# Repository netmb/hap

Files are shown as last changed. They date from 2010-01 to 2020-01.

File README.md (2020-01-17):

# This project is no longer maintained! We recommend esphome.io in combination with home-assistant.io as an alternative.
## If you build a lot of HAP-Actors like "HAP-Relais" and would like to continue using it: Use esphome.io with an ESP32 as an drop-in replacment. Works like charm!
Home Automation Project

HA using Atmel-AVR and Web 2.0.



Take a look at the [Wiki-Sites](https://github.com/netmb/hap/wiki) for more Information or if you want to jump-start, check the Installation-Instruction: [Installation](https://github.com/netmb/hap/wiki/Installation)

Some more documenation:

[HAP-CU-TechDok.pdf](https://github.com/netmb/hap/blob/master/doc/HAP-CU-TechDok.pdf?raw=true)

[Hap_QuickStart.pdf](https://github.com/netmb/hap/blob/master/doc/Hap_QuickStart.pdf?raw=true)

If you need support, check out: [hap-users group](https://groups.google.com/d/forum/hap-users)

This thread is also a good source: http://www.mikrocontroller.net/topic/148340#new

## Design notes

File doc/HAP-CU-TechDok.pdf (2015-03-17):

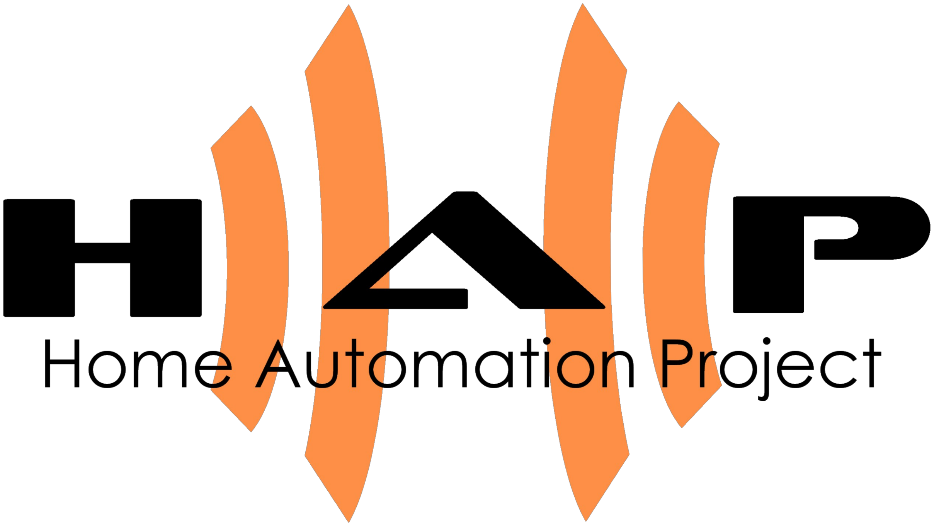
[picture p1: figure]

# Control Unit

Technische Dokumentation

Autor: | Dipl.-Ing. Holger Heuser
Revision: | 1.0 (1)
Zuletzt geändert: | 25. März 2008

Inhaltsverzeichnis

- 2 -

- 3 -

Abbildungsverzeichnis

- 4 -

Tabellenverzeichnis

Tabelle 4.15: AS Codierung der Zeitbasis bei der zeitgesteuerten Weiterleitung.......84

- 5 -

## 1 Einleitung

Die Control Unit stellt innerhalb des HAP (Home Automation Project) die zentrale Komponente dar. Sie nimmt unterschiedlichste Steuer- und Regelaufgaben wahr und arbeitet dabei völlig autonom. So ist es mit Hilfe der Control Unit möglich, Leuchten zu steuern bzw. zu dimmen, alle möglichen Arten von Geräten zu steuern und zu schalten, sowie Messwerte von Sensoren zu erfassen, zu verarbeiten oder weiterzuleiten. Sie bietet eine Infrarot-Schnittstelle zu ihrer Steuerung an und kann
mit | Hilfe | eines | LCD | (Liquid | Crystal | Display) | und | entsprechenden
Eingabekomponenten eine Mensch-Maschine-Schnittstelle realisieren. So lassen sich prinzipiell alle im Haus bzw. in der Wohnung anfallenden Steuerungen und Regelungen realisieren.

Da die Zahl der anschließbaren Geräte durch die Anzahl an Ein- und Ausgängen des verwendeten Mikrocontrollers begrenzt ist, werden für eine Heimsteuerung gewöhnlich mehrere Control Units benötigt. Damit diese untereinander Informationen über den Status der jeweils angeschlossenen Geräte und weitere Nachrichten, die zum gemeinsamen Bewältigen einer komplexen Steueraufgabe nötig sind,
austauschen | können, | besitzt | eine | Control | Unit | mehrere
Kommunikationsschnittstellen bzw. kann mit diesen bestückt werden. So wird in den meisten Fällen auf einen CAN-Bus (Controller Area Network Bus) zurückgegriffen. Es ist aber auch die Kommunikation über Funk möglich.

Für Konfigurationsarbeiten, zur Verwaltung der kompletten Steuerungsanlage, zum Fehlermanagement und zur Steuerung von Geräten über Webbrowser, PDAs, Handys etc. wird eine Central Control Unit eingesetzt, bei der es sich um ein Serversystem mit spezieller Steuerungssoftware handelt. Damit eine Control Unit mit der Central Control Unit kommunizieren kann, wird eine speziell konfigurierte Control Unit eingesetzt, die als Brücke zwischen dem von den Control Units verwendeten Kommunikationssystem und der seriellen oder USB-Schnittstelle der Central Control Unit arbeitet.

Im Allgemeinen wird man die Control Units in Hutschienengehäusen in der Elektroverteilung unterbringen. Dies ist insbesondere dann sinnvoll, wenn zur Ansteuerung von Geräten Leistungsstufen wie Relais oder Dimmerstufen benötigt werden. Die räumliche Nähe erleichtert dann die Verkabelungsarbeiten erheblich. Die

- 6 -

Bauform der Control Unit lässt aber auch die Unterbringung in Schalterdosen zu, was vor allem für die Realisierung einer Mensch-Maschine-Schnittstelle sinnvoll ist, da sich eine solche meist in den Wohnräumen befindet.

Welche Geräte wo und wie an die Control Unit angeschlossen werden können, ist bis auf wenige Restriktionen frei konfigurierbar. Des weiteren ist das Verhalten einer Control Unit in ihrer Umgebung durch komplexe Konfigurationsmöglichkeiten einstellbar. Insbesondere die Konfiguration einer Mensch-Maschine-Schnittstelle ist recht aufwändig. Zur besseren Handhabung und zur Vermeidung von Fehlern steht ein Softwarewerkzeug für diese Arbeiten zur Verfügung, welches die Konfiguration einer Control Unit recht komfortabel gestaltet und nicht nur eine Control Unit dabei berücksichtigt, sondern das System als Ganzes. Die von diesem Werkzeug erzeugten Konfigurationen werden dann in EEPROMs auf der Control Unit gespeichert, so dass diese prinzipiell autark, also ohne die Central Control Unit funktionieren können und auch nach einem Stromausfall problemlos wieder funktionieren.

Der Aufbau und die Funktionsweise der Hardware wird im nächsten Kapitel beschrieben (siehe Kapitel 2 Hardware). Es folgt die Beschreibung des grundlegenden Verhaltens einer Control Unit, ihr Kommunikationsverhalten sowie deren Handhabung hinsichtlich Konfiguration, Management und Wartung (siehe Kapitel 3 Steuerung). Die unterschiedlichen Software Komponenten, die auf einer Control Unit integriert sein können, werden im Kapitel 4 Komponenten erörtert. Schließlich finden sich in Kapitel 5 Tabellen und Übersichten noch einmal Zusammenfassungen aus vorigen Kapiteln bzw. sind einige Sachverhalte anders zusammengestellt, um einen schnelleren Überblick zu bekommen bzw. schnell gezielte Informationen zu finden.

- 7 -

## 2 Hardware

Unter einer Control Unit wird im Allgemeinen nur die fertig bestückte Platine verstanden. Ob diese in einem Hutschienengehäuse zum Einbau in der Elektroverteilung, in einem gewöhnlichen Gehäuse, als Aufsatz einer Leistungsstufe oder direkt in einer Schalterdose untergebracht wird, ist vom jeweiligen Einsatzzweck abhängig. Unten stehende Abbildung zeigt die Control Unit in Draufsicht.

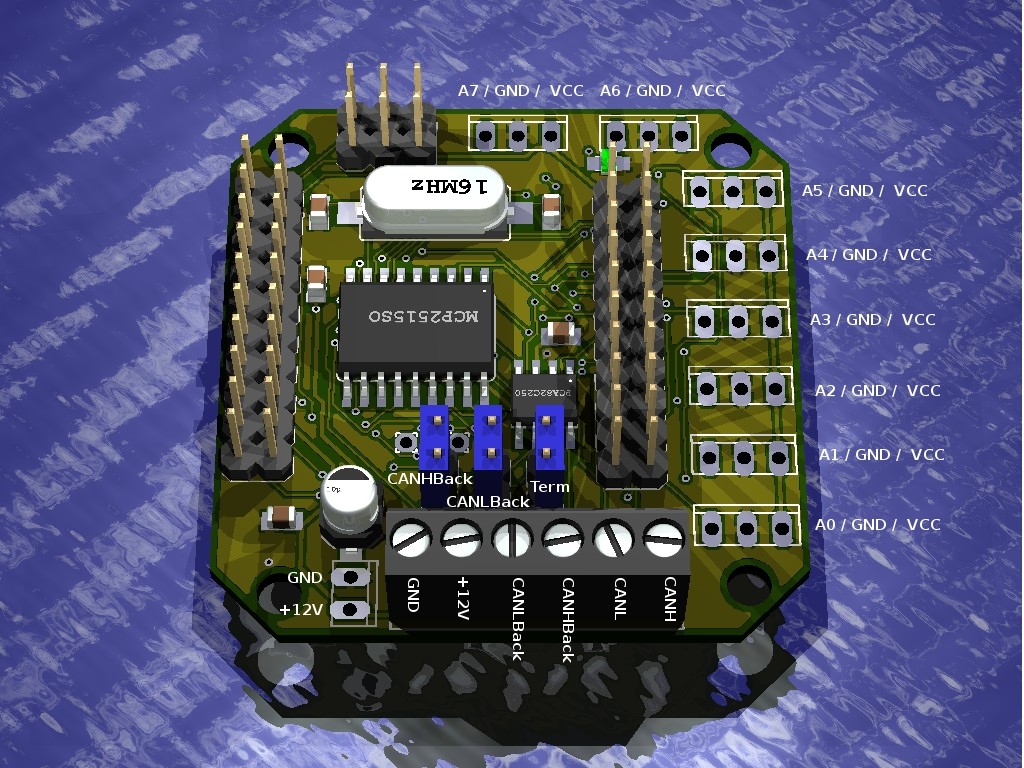
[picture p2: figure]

### 2.1 Schaltung

Der Schaltplan der Control Unit ist auf der nächsten Seite dargestellt. Auf Basis dieses Plans sollen die wichtigsten Komponenten der Unit beschrieben und im folgenden Kapitel auch die Pin-Konfiguration erläutert werden.

- 8 -

Abb. 2.1: Control Unit in der Draufsicht

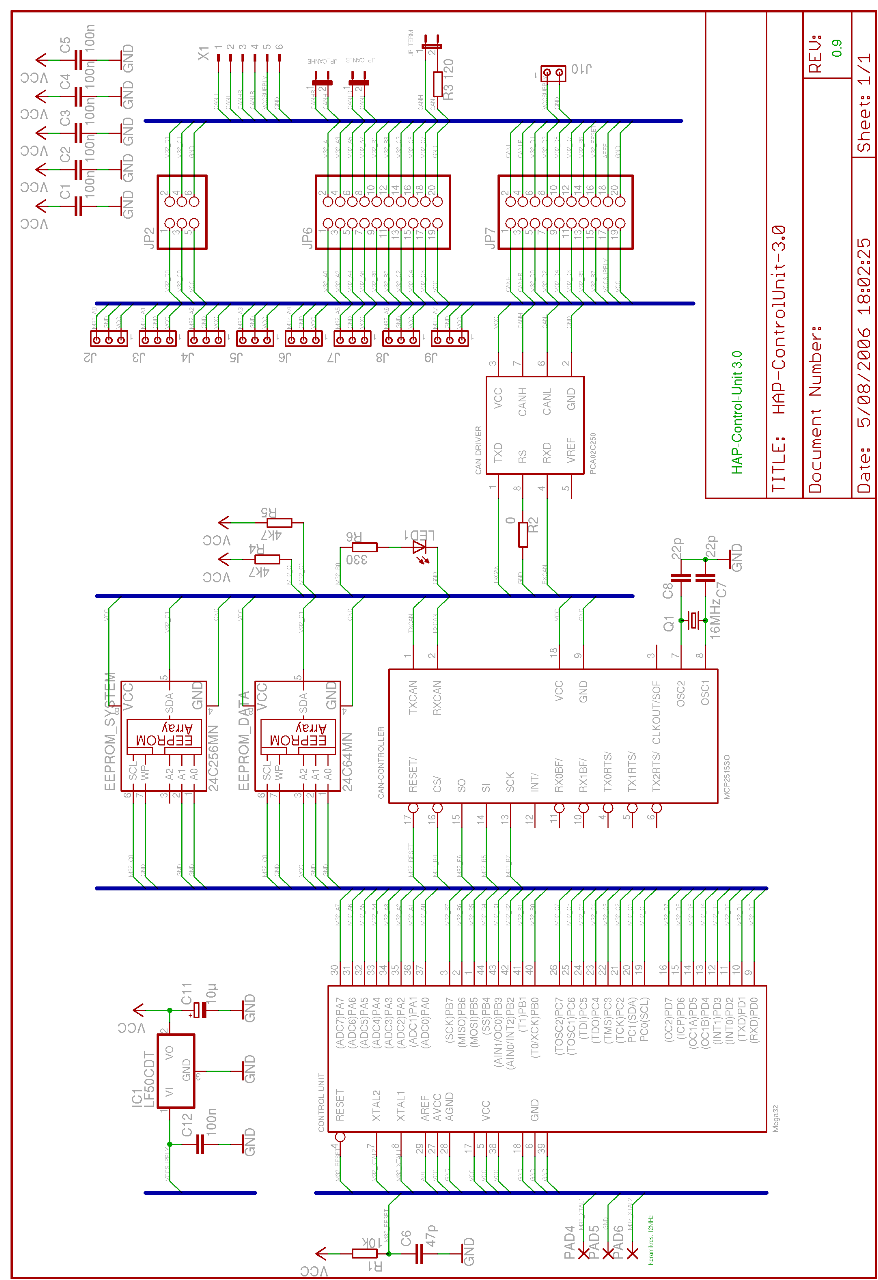
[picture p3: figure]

- 9 -

Abb. 2.2: Schaltplan der Control Unit

In den folgenden Ausführungen wird davon ausgegangen, dass der Schaltplan im Querformat vorliegt, die Schrift also korrekt zum Betrachter ausgerichtet ist. Zu den Details, die auf diesem Plan nicht mehr zu erkennen sind, sei auf den Originalplan verwiesen.

In der oberen linken Ecke des Plans erkennt man die Spannungsversorgung, die mit Hilfe eines Festspannungsreglers die außen anliegende 12 V Gleichspannung in eine intern verwendete 5 V Gleichspannung (VCC) wandelt und diese glättet.

Darunter findet man das Herzstück der Control Unit, den Mikrocontroller. Hier wird ein ATmega32 von ATMEL verwendet. Der Reset-Pin wird nicht verwendet und deshalb über R1 mit VCC verbunden. PAD4 bis PAD6 dienen der Aufnahme eines externen Quarz. Dieser muss eine Frequenz von 12 MHz aufweisen und legt damit die Taktfrequenz des Mikrocontroller auf eben diesen Wert fest.

In der Bildmitte oben sieht man zwei externe EEPROMs der Größe 64 KBit und 256 KBit, die über ein TWI (Two Wire Interface) mit dem Mikrocontroller verbunden sind. Neben dem im Mikrocontroller integriertem EEPROM dienen diese dem Speichern der Konfigurationsdaten der Control Unit und deren Firmware Update.

Rechts unterhalb der EEPROMs ist eine LED zu erkennen, die als optische Signaleinrichtung dient und mit Pin B0 des Mikrocontrollers verbunden ist. An den selben Pin kann auch ein Summer als akustische Unterstützung angeschlossen werden (siehe auch Kapitel 4.3 Buzzer).

Direkt unterhalb der EEPROMS findet man den CAN-Controller (Controller Area Network Controller), der zur Steuerung des CAN-Bus benötigt wird. Dieser bezieht seine Taktfrequenz von einem separatem 16 MHz Quarz (unten rechts) und ist über ein SPI (Serial Peripheral Interface) mit dem Mikrocontroller gekoppelt. Über den rechts daneben befindlichen CAN-Treiber wird dann direkt der CAN-Bus betrieben.

Die drei Jumper am rechten Bildrand stehen von oben nach unten für CANHBack, CANLBack und CANTerm. Ist CANHBack gesteckt, so wird der Anschluss CANH an der Schraubleiste X1 nach CANHBack geschliffen, ansonsten nicht. Für CANLBack gilt dies analog. Der Jumper CANTerm terminiert den CAN-Bus, das heißt, R3 wird zwischen CANH und CANL geschaltet.

- 10 -

### 2.2 Pin-Konfiguration

Die Control Unit besitzt unterschiedliche Steckverbinder und Klemmleisten, die alle für einen spezifischen Zweck zugeschnitten worden sind. Im Folgenden wird deren Belegung und Verwendung näher beschrieben (siehe als Referenz hierzu Abbildung 2.1 Control Unit in der Draufsicht, Kapitel 2.1 Schaltung und 2.3 Dimensionen und Platinenlayout).

Die Klemmleiste X1 dient dem Anschluss an den CAN-Bus. Von links nach rechts ergibt sich die Belegung der Klemmleiste wie folgt.

Klemme | Beschreibung
1 | Ground
2 | Versorgungsspannung (+12 V)
3 | CAN Low Back
4 | CAN High Back
5 | CAN Low
6 | CAN High

Tabelle 2.1: Belegung der CAN Klemmleiste

Wird die Control Unit über den CAN-Bus mit Strom versorgt, so ist die Versorgungsspannung an den Klemmen 1 und 2 anzulegen. Soll die Control Unit über eine Stichleitung an den CAN-Bus angeschlossen werden, so sind die Adern CAN Low und CAN High an Klemme 5 und 6 anzulegen. Soll der CAN-Bus über die Control Unit geschliffen werden, so sind die entsprechenden Jumper zu setzen (siehe Kapitel 2.1 Schaltung) und über die Klemmen 3 und 4 ist der Bus wieder abzugreifen.

Alternativ | zur | Spannungsversorgung | über | den | CAN-Bus | kann | die
Versorgungsspannung auch über den 2-pol. Platinensteckverbinder J10 zugeführt werden (außen liegender Pin ist +12 V, innen liegender Pin ist Ground). Wird die Control Unit aber über den CAN-Bus versorgt, so kann die Versorgungsspannung über J10 für andere Zwecke abgegriffen werden.

Insbesondere, weil der Anschluss analoger und digitaler Sensoren auf Port A des Mikrocontrollers beschränkt ist (siehe Kapitel 4.9 Analoge Eingänge und 4.10 Digitale Eingänge), ist jeder Pin von Port A über einen eigenen Platinensteckverbinder, an

- 11 -dem zusätzlich auch Ground und VCC anliegt, nach außen geführt. Folgende Tabelle zeigt die Stift-Belegung von unten nach oben und von rechts nach links.
Steckverb. | Links | Mitte | Rechts
J2 | Pin A0 | Ground | VCC
J3 | Pin A1 | Ground | VCC
J4 | Pin A2 | Ground | VCC
J5 | Pin A3 | Ground | VCC
J6 | Pin A4 | Ground | VCC
J7 | Pin A5 | Ground | VCC
J8 | Pin A6 | Ground | VCC
J9 | Pin A7 | Ground | VCC

Tabelle 2.2: Belegung der 3-pol. Platinensteckverbinder

Die restlichen Pins des Mikrocontrollers sind über die drei Stiftleisten nach außen geführt. Über passende Pfostenstecker kann dann ein Flachbandkabel angeschlossen werden. Die Stift-Belegung der 6-pol. Leiste JP2, die am oberen Bildrand zu erkennen ist, kann folgender Tabelle entnommen werden. Die Stifte werden von unten nach oben und von links nach rechts gezählt.

Stift | Beschreibung
1 | Pin D0
2 | Pin D1
3 | Pin C0
4 | Pin C1
5 | VCC
6 | Ground

Tabelle 2.3: Belegung der Stiftleiste JP2

Die 20-pol. Leiste JP6 befindet sich in der Bildmitte. Es wird von rechts nach links und von unten nach oben nummeriert.

- 12 -

Stift | Beschreibung
1 | Pin A0
2 | Pin A1
3 | Pin A2
4 | Pin A3
5 | Pin A4
6 | Pin A5
7 | Pin A6
8 | Pin A7
9 | Pin B0
10 | Pin B1
11 | Pin B2
12 | Pin B3
13 | Pin C2
14 | Pin C3
15 | Pin C4
16 | Pin C5
17 | Pin C6
18 | Pin C7
19 | VCC
20 | Ground

Tabelle 2.4: Belegung der Stiftleiste JP6

Die 20-pol. Leiste JP7 befindet sich am linken Bildrand. Es wird von rechts nach links und von unten nach oben nummeriert.

- 13 -

Stift | Beschreibung
1 | CAN High
2 | CAN Low
3 | CAN High Back
4 | CAN Low Back
5 | Pin D0
6 | Pin D1
7 | Pin D2
8 | Pin D3
9 | Pin D4
10 | Pin D5
11 | Pin D6
12 | Pin D7
13 | Pin B5
14 | Pin B6
15 | Pin B7
16 | Reset
17 | Versorgungsspannung (+12 V)
18 | AREF
19 | VCC
20 | Ground

Tabelle 2.5: Belegung der Stiftleiste JP7

Zu Stift 16 und 18 sei auf das Datenblatt des Mikrocontrollers Kapitel System Control and Reset und Analog to Digital Converter verwiesen.

- 14 -

### 2.3 Dimensionen und Platinenlayout

Die Maße der Control Unit, insbesondere die Position der Bohrlöcher, können nachstehender Skizze entnommen werden. Der linke Teil zeigt die Draufsicht, wobei die Platine die selbe Orientierung aufweist, wie in Abb. 2.1: Control Unit in der Draufsicht. In der Seitenansicht rechts ist die Bestückung der Platine nur grob skizziert, wobei die Maße jedoch mit den maximalen realen Maßen übereinstimmen.

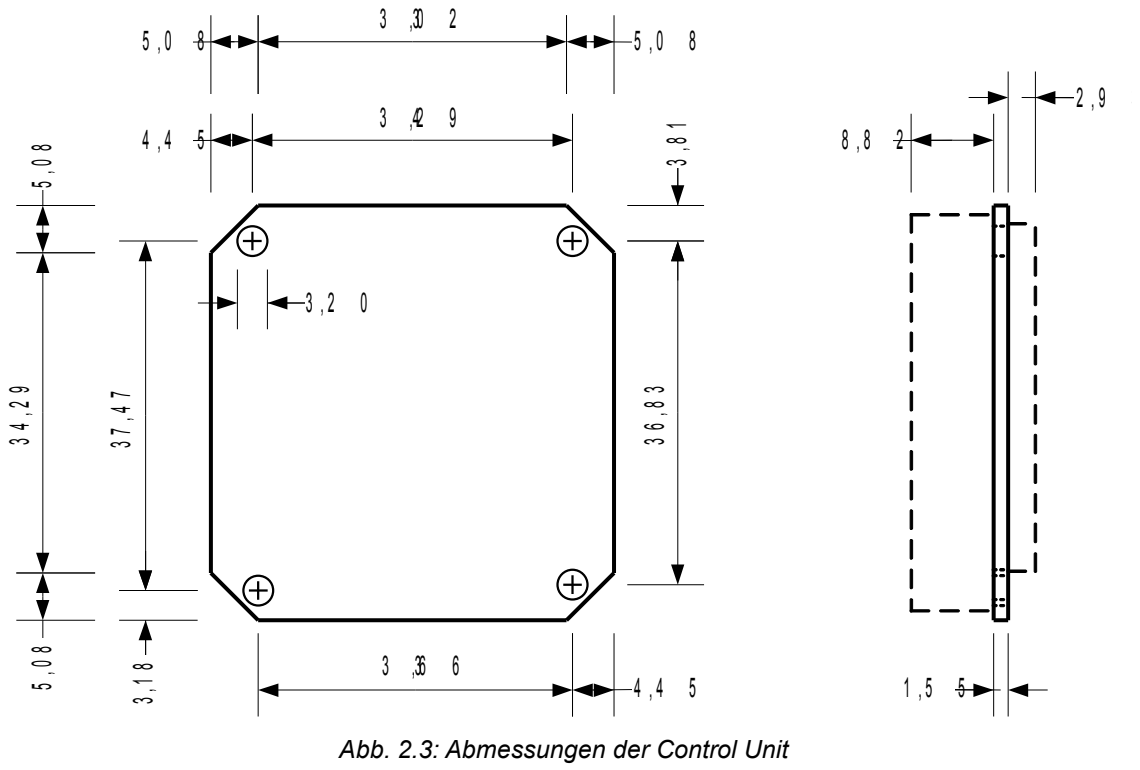
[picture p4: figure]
Abb. 2.3: Abmessungen der Control Unit

- 15 -

Die folgende Abbildung zeigt das Platinenlayout von oben. Alle Klemm- und Steckverbindungen befinden sich auf der Oberseite der Platine. Man erkennt ferner in der Bildmitte den CAN-Controller, rechts daneben den CAN-Treiber und oberhalb vom CAN-Controller den 16 MHz Quarz für den Controller-Takt.

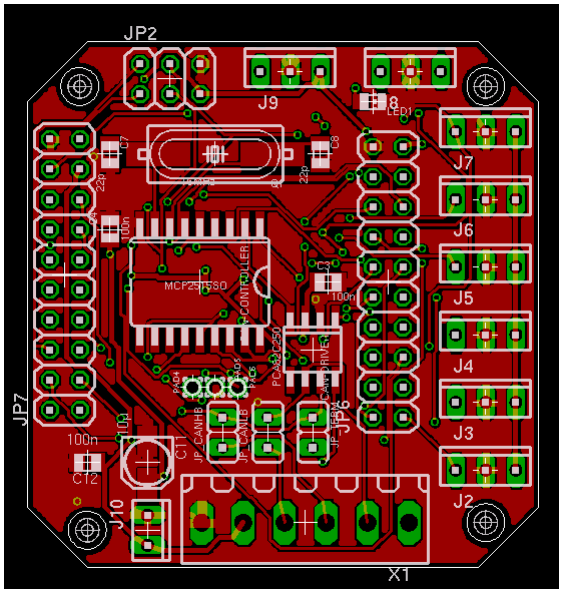
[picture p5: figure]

- 16 -

Abb. 2.4: Platinenlayout der Control Unit Oberseite

Der Mikrocontroller ist auf der Unterseite angebracht. Auf dem Layout findet man ihn in der Bildmitte. Oberhalb davon sind die beiden EEPROMs zu erkennen und in der linken unteren Ecke der Festspannungsregler.

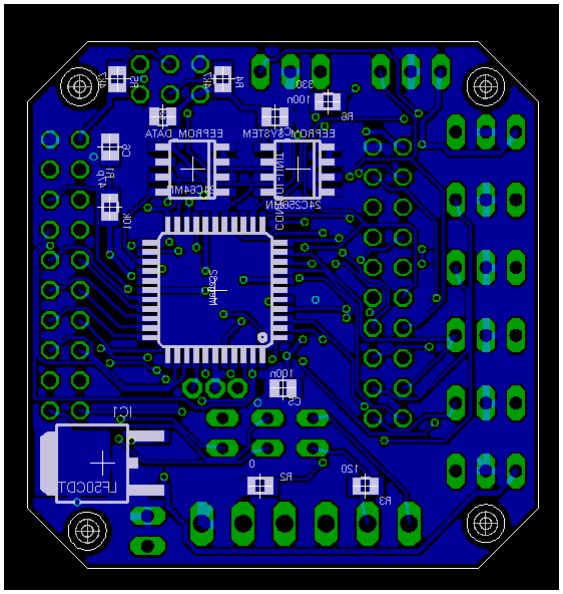
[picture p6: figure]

- 17 -

Abb. 2.5: Platinenlayout der Control Unit Unterseite

## 3 Steuerung

Das Steuermodul bestimmt das grundsätzliche Verhalten einer Control Unit, es steuert und verbindet die einzelnen Komponenten, es stellt die Kommunikation mit anderen Control Units und der Central Control Unit sicher und bietet die Möglichkeit des Firmware-Updates. Es handelt sich um eine reine Softwarekomponente, die in jeder Firmware enthalten ist.

### 3.1 Kommunikation

Zur Kommunikation der Control Units untereinander und mit der Central Control Unit werden zwischen diesen Datenpakete ausgetauscht. Dies kann über verschiedene Schnittstellen - z. B. CAN-Bus, USB-Schnittstelle, Funk - erfolgen. Ein solches Datenpaket hat immer eine Länge von acht Byte und hat folgenden prinzipiellen Aufbau:

VLAN | Source | Dest | MType | Device | Value0 | Value1 | Value2

Abb. 3.1: Aufbau eines Datenpakets

- VLAN
Dieses Byte kennzeichnet das virtuelle LAN – Local Area Network – in dem sich das Datenpaket bewegen soll.
- Source
Source ist die Moduladresse der Control Unit bzw. der Central Control Unit, die das Datenpaket gesendet hat.
- Dest
Dest ist die Moduladresse der Control Unit bzw. der Central Control Unit, an die das Datenpaket geschickt werden soll.
- MType
Dieses Byte spezifiziert den Typ des Datenpakets. Es lässt z. B. erkennen, ob es sich um einen Steuer- oder einen Konfigurationsbefehl handelt.
- Device
- 18 -

Dieses Byte gibt an, für welches auf einer Control Unit konfigurierten Geräts das Paket bestimmt ist bzw. welches Gerät das Paket initiiert hat. Ob es sich hierbei um eine Quell- oder Zieladresse handelt wird dabei durch MType bestimmt. In einigen Ausnahmefällen wird dieses Byte aber nicht als Geräteadresse verwendet, sondern trägt vom jeweiligen Anwendungsfall abhängige Informationen, was auch durch MType bestimmt wird.

- Value0 – Value2
Diese drei Bytes werden je nach Datenpaket mit ganz bestimmten Werten gefüllt, die sich so global nicht beschreiben lassen.

Empfängt ein Modul ein Datenpaket und verarbeitet es korrekt, so quittiert es dieses, indem es das Paket mit den selben Werten an den Sender zurückschickt. Als Source wird dabei die eigene Moduladresse und als Dest die des Senders eingesetzt. Der MType wird um 1 inkrementiert. Konnte das Paket nicht erfolgreich verarbeitet werden, wird MType um 2 inkrementiert. In Ausnahmefällen wird von diesem Vorgehen abgewichen. Dann wird an den entsprechenden Stellen explizit darauf hingewiesen.

Im folgenden werden Datenpakete immer durch acht Zahlenwerte dargestellt, die durch Leerzeichen getrennt sind:

34 1 20 0 200 80 100 0

Hier ist 34 das VLAN, in dem sich das Datenpaket bewegt, 1 die Adresse des sendenden Moduls, 20 die Adresse des empfangenden Moduls und die 0 steht für einen Set-Befehl, der an das Gerät mit der Adresse 200 gerichtet ist. Dieses soll innerhalb einer bestimmten Zeit, die in den letzten beiden Bytes codiert ist, den Wert 80 annehmen.

Sind einige dieser Bytes in der jeweiligen Beschreibung nicht genau anzugeben, so werden sie durch entsprechende Variablen dargestellt:

VLAN Source Dest 0 Device 80 100 0

### 3.1.1 Virtuelle LANs

Jedes lokale physikalische Netzwerk – z. B. ein CAN-Bus oder ein auf einer

- 19 -bestimmten Frequenz betriebenes Funknetz – kann logisch in kleinere Einheiten zerlegt werden, zwischen denen prinzipiell kein Datenaustausch stattfinden kann. Diese logischen Netzwerke verhalten sich in jeder Hinsicht wie ihre physikalischen Äquivalente.

Zwei Module können nur dann Datenpakete untereinander austauschen, wenn die jeweiligen Schnittstellen, über die der Austausch stattfindet, sich im selben VLAN befinden. Das bedeutet, jeder Schnittstelle wird eine VLAN-ID zugeordnet. Und wenn ein Datenpaket über eine Schnittstelle versendet wird, dann wird eben diese ID in das erste Feld des Pakets eingetragen. Ebenso kann ein Datenpaket nur über eine Schnittstelle empfangen werden, dessen VLAN-ID mit der im Paket übereinstimmt.

Zur Konfiguration der VLAN-IDs sei auf die entsprechenden Kapitel verwiesen, in denen die Schnittstellen beschrieben werden.

### 3.1.2 Modul-Adressierung

Jedes Modul wird über seine eindeutige Modul-Adresse angesprochen. Das heißt, nur wenn eben diese Adresse im Dest-Feld eines Datenpakets steht, wird das Modul dieses Paket empfangen. Ebenso sorgt die Steuerung dafür, dass diese Adresse ins Source-Feld eines Datenpakets eingetragen wird, wenn ein solches Paket vom Modul versendet wird.

Die Moduladresse kann über folgenden Befehl konfiguriert werden:

VLAN Source Dest 76 5 ModulAddress 0 0

Ein noch nicht konfiguriertes Modul hat die Adresse 0.

Die Moduladresse kann Werte zwischen 0 und 239 annehmen. Bei den Adressen von 240 bis 255 handelt es sich um Multicast-Adressen, welche somit als Moduladressen nicht zulässig sind. Jede dieser Adressen kann gewissermaßen als Gruppe aufgefasst werden. Wird ein Datenpaket an eine solche Gruppe adressiert, so empfängt dieses Paket jedes Modul, welches Mitglied dieser Gruppe ist. Die Mitgliedschaft in den einzelnen Gruppen kann über folgenden Befehl festgelegt werden:

VLAN Source Dest 76 13 LByte HByte 0

- 20 -

LByte und HByte bilden zusammen einen 16-Bit Wert, wobei ein gesetztes Bit die Mitgliedschaft in der entsprechenden Gruppe kennzeichnet. Bit0 entspricht dabei der Adresse 240, Bit1 der Adresse 241, usw..

Per Voreinstellung ist jedes Modul und ausschließlich Mitglied der Gruppe 255, wobei sich diese Adresse dann wie eine Broadcast-Adresse verhält.

### 3.1.3 Magic Packet

Ist ein Modul nicht mehr erreichbar, weil die aktuelle Moduladresse nicht bekannt ist oder gibt es innerhalb eines virtuellen LANs mindestens zwei Module mit der gleichen Adresse, kann das entsprechende Modul angesprochen bzw. die Eindeutigkeit wieder hergestellt werden, indem ein so genanntes Magic Packet eingesetzt wird. Hiermit kann dem Modul eine neue Moduladresse zugewiesen werden ohne die aktuelle Adresse als Dest zu verwenden:

VLAN Source 255 124 ModulAddress HwAddr1 HwAddr2 HwAddr3

Hierbei ist ModulAddress die neu zu vergebende Moduladresse und HwAddrx das x-te Byte der Hardware-Adresse des Moduls. Die Hardware-Adresse ist 4 Byte lang, wobei die einzelnen Bytes von 0 bis 3 nummeriert werden. Sie findet sich auf einem Aufkleber auf der Platine der Control Unit, wobei die einzelnen Bytes durch Punkte getrennt sind.

### 3.1.4 Central Control Unit Adresse

Die Central Control Unit wird wie eine Control Unit über eine Moduladresse angesprochen. Damit ein Modul initiierend mit der Central Control Unit kommunizieren kann, muss deren Adresse dem Modul bekannt gemacht werden. Dies geschieht mit folgendem Konfigurationsbefehl:

VLAN Source Dest 76 6 CCUAddress 0 0

Der Wertebereich für die CCUAddress unterliegt dabei den selben Restriktionen wie die Moduladresse und liegt damit zwischen 0 und 239. Die Voreinstellung ist 255 und muss damit unbedingt geändert werden.

- 21 -

### 3.1.5 Bridge-Mode

Eine Control Unit lässt sich auch als Vermittler zwischen verschiedenen LANs einsetzen, wenn sie im Bridge-Mode betrieben wird. Dieser lässt sich mit

VLAN Source Dest 76 10 Bridge-Mode 0 0

einstellen, wobei Bridge-Mode=0 für den Normalbetrieb und Bridge-Mode=1 für den aktivierten Bridge-Mode steht. Die Voreinstellung ist Bridge-Mode=0.

Wird eine Control Unit im Bridge-Mode betrieben, so wird jedes Datenpaket, welches über eine bestimmte Schnittstelle empfangen wird und nicht für die Control Unit selbst bestimmt ist, über alle anderen verfügbaren Schnittstellen unverändert weiter geschickt. Lediglich die VLAN-ID wird gemäß der auf der Schnittstelle konfigurierten angepasst.

Empfangene Broadcasts und Multicasts werden grundsätzlich weiter versendet.

### 3.1.6 Empfangspuffer

Es kann vorkommen, dass eine Control Unit schneller Datenpakete empfängt, als sie diese verarbeiten kann. Zu diesem Zweck ist jede Control Unit mit einem Empfangspuffer ausgestattet, der per Voreinstellung 4 Pakete zwischenspeichern kann. Die Länge dieses Empfangspuffers lässt sich über folgenden Befehl festlegen:

VLAN Source Dest 76 96 Length 0 0

Length spezifiziert dabei die Länge des Empfangspuffers. Damit die Einstellung wirksam wird, ist auf dem Modul ein Reset auszuführen.

Bei der Länge ist ein Kompromiss zu finden zwischen der Betriebssicherheit – der Puffer muss groß genug sein, damit keine Pakete verloren gehen – und den Anwendungsmöglichkeiten der Control Unit – jedes zwischen zu speichernde Paket benötigt 8 Byte RAM, der statisch verwaltet wird und deshalb anderen Komponenten nicht mehr zur Verfügung steht.

### 3.1.7 Steuerbefehle

Dieser Nachrichtentyp wird verwendet, um ein an die Control Unit angeschlossenes

- 22 -

Gerät auf einen bestimmten Wert zu setzen. Gegebenenfalls werden weitere Steuerparameter übergeben. Ein Steuerbefehl hat folgende allgemeine Form:

VLAN Source Dest 0 Device Value LParam HParam

Device ist die Geräte-Adresse des zu steuernden Geräts, Value der Wert, den das Gerät annehmen soll und LParam und HParam bilden zusammen einen 16-Bit Wert der Steuerparameter enthält. Jedes Gerät bzw. jede Komponente der Software behandelt die letzten drei Bytes etwas anders. Hier sei auf die entsprechenden Kapitel verwiesen.

### 3.1.8 Abfragen

Um den Wert bzw. den Status, den ein Gerät aktuell hat, abzufragen, kommt dieser Nachrichtentyp zum Tragen. Die allgemeine Form ist:

VLAN Source Dest 8 Device 0 0 Select

Device ist die Geräte-Adresse des Geräts, dessen Status abgefragt werden soll. Manche Geräte haben mehrere Werte bzw. Status, dann wird durch Select der entsprechende Wert selektiert. Beantwortet wird eine solche Nachricht wie folgt:

VLAN Source Dest 9 Device LValue HValue Select

Es ändert sich also lediglich der Nachrichtentyp und in dem 16-Bit Wert, der durch LValue und HValue gebildet wird, ist das Ergebnis der Abfrage enthalten. Auch hier werden die letzten drei Byte von jeder Komponente individuell genutzt, was den entsprechenden Kapiteln zu entnehmen ist.

### 3.1.9 Statusmeldungen

Statusmeldungen werden von unterschiedlichsten Geräten einer Control Unit beim Eintreffen bestimmter Ereignisse generiert. Andere Komponenten, wie z. B. die autonome Steuerung, verarbeiten dann solche Statusmeldungen. Die allgemeine Form einer Statusmeldung ist die folgende:

VLAN Source Dest 16 Device LValue HValue Ext

Device ist die Geräte-Adresse des Geräts, welches die Statusmeldung auslöste,

- 23 -

LValue und HValue bilden zusammen einen 16-Bit Wert, der normalerweise dem aktuellen Status des Geräts entspricht und Ext ist eine komponentenabhängige Erweiterung. Insbesondere die letzten drei Byte werden von den verschiedenen Komponenten unterschiedlich verwendet, was in den entsprechenden Kapiteln nachzulesen ist.

### 3.1.10 Makros

Makros sind zunächst einmal nichts anderes als ein bestimmter Nachrichtentyp. Ein Makro hat folgenden Aufbau:

VLAN Source Dest 24 0 LMakro HMakro 0

LMakro und HMakro bilden zusammen dabei einen 16-Bit Wert, der die Makro-Nummer spezifiziert.

Unterschiedliche Komponenten der Control Unit können Makros generieren, z. B. die Infrarotschnittstelle und unterschiedliche Komponenten können auf den Empfang eines Makros reagieren, z. B. die autonome Steuerung. Details hierzu sind den entsprechenden Kapiteln zu entnehmen.

Auch die Central Control Unit kann Makros generieren und auch auf sie reagieren, indem gewöhnlich eine komplexe Steuer- bzw. Regelaufgabe durch sie angestoßen wird.

### 3.1.11 Fehlerbehandlung

Neben der „normalen“ Fehlerbehandlung, wie sie in Kapitel 3.1 Kommunikation beschrieben ist, gibt es noch einige Sonderfälle, die in diesem Kapitel erörtert werden sollen.

Wird durch eine lokale Ansteuerung – Autonome Steuerung, Bedienoberfläche oder Infrarot Fernbedienung – ein Fehler beim Setzen eines Werts provoziert, so schickt die entsprechende Control Unit eine Fehlermeldung folgender Gestalt:

VLAN Source Dest 2 Device Value LDelay HDelay

Source und Dest sind hier gleich und repräsentieren die Moduladresse der Control Unit, auf der der Fehler aufgetreten ist. Dies leuchtet ein, wenn man sich verdeutlicht,

- 24 -dass in Source die Control Unit steht, die angesteuert wurde und in Dest die ansteuernde Control Unit, was bei einer lokalen Ansteuerung das selbe ist. Die restlichen Werte entsprechen denen eines klassischen Setz-Befehls und sind selbstredend.

Steuert eine lokale Control Unit eine entfernte andere oder richtet an sie eine Anfrage und bekommt von dieser keine Antwort, so setzt die lokale Control Unit, wie folgt eine Fehlermeldung ab:

VLAN LModul CCU 127 1 RModul RMType RDevice

LModul ist die Adresse des lokalen Moduls, CCU die Adresse der Central Control Unit, RModul ist die Adresse des entfernten Moduls, RMType ist der Nachrichtentyp der ursprünglichen Nachricht und RDevice das entsprechende Gerät. Die 127 repräsentiert einen Protokollfehler und die 1 steht für „No Response“.

Wird versucht ein Gerät anzusteuern, welches zu dieser Zeit nicht bereit ist – z. B. ein Rollladen, der gerade dabei ist in eine zuvor bestimmte Position zu fahren, reagiert die zugehörige Control Unit mit folgender Meldung:

VLAN Modul CCU 127 2 Device 0 0

Modul ist dabei die Adresse der entsprechenden Control Unit, CCU die Adresse der Central Control Unit und Device die Geräte-Adresse. Die 127 repräsentiert einen Protokollfehler und die 2 steht für „Device Busy“.

### 3.2 Resets und Neustarts

Es gibt insgesamt drei verschiedene Möglichkeiten auf einer Control Unit einen Reset auszuführen. Ein normaler Software-Reset – er wird im Allgemeinen nur als Reset bezeichnet – wird mit dem Befehl

VLAN Source Dest 76 1 0 0 0

eingeleitet. Dadurch initialisiert sich die Software neu und startet mit den aktuellen Konfigurationsparametern. Diese werden jedoch nicht aus dem EEPROM geladen. Das heißt, wurden Parameter geändert aber noch nicht gespeichert, so werden sie dennoch berücksichtigt und nicht durch gespeicherte Parameter überschrieben. Einige Änderungen der Konfiguration verlangen im Anschluss einen solchen Reset

- 25 -um wirksam zu werden. In diesen Fällen wird dann explizit darauf hingewiesen.

Einen so genannten Full-Reset leitet man mit dem Befehl

VLAN Source Dest 76 2 0 0 0

ein. Die Control Unit wird daraufhin komplett neu gestartet, das heißt, es findet auch eine Hardware-Initialisierung statt. Dieser Reset entspricht dem Aus- und wieder Einschalten des Moduls. Geänderte Konfigurationsparameter, die noch nicht gespeichert wurden, gehen dabei verloren.

Um die Control Unit mit den voreingestellten Konfigurationsparametern neu zu starten (Konfigurationsreset) verwendet man folgenden Befehl:

VLAN Source Dest 76 3 0 0 0

Die Control Unit befindet sich danach in dem selben Zustand wie nach dem aller ersten Start nach der Auslieferung.

### 3.3 Konfigurationsmanagement

Möchte man die aktuelle Konfiguration dauerhaft im EEPROM speichern, so dass sie auch nach einem Neustart wieder zur Verfügung steht, so wendet man folgenden Befehl an:

VLAN Source Dest 76 8 0 0 0

Um die Konfiguration aus dem EEPROM zu laden und damit die aktuelle Konfiguration zu überschreiben, kommt folgender Befehl zur Anwendung:

VLAN Source Dest 76 9 0 0 0

Im Allgemeinen muss danach ein Reset durchgeführt werden, um die geladene Konfiguration aktiv werden zu lassen. Es sei denn, die geladene Konfiguration unterscheidet sich von der vorherigen nur durch Parameter, die einen solchen Reset nicht erfordern.

Mit welcher Konfiguration ein Modul nach dem Start bzw. Neustart hochfährt, wird durch den Startmodus festgelegt, der wie folgt gesetzt werden kann:

VLAN Source Dest 76 4 StartMode 0 0

- 26 -

Damit die Einstellung nach dem Neustart auch greift, muss die Konfiguration vorher gespeichert werden. Ist StartMode=217, so startet das Modul mit der Konfiguration, die sich zu diesem Zeitpunkt im EEPROM befindet. Ist der StartMode=179, so startet das Modul mit der Default-Konfiguration. Lediglich die Konfigurationsparameter, die die Steuerung, den Buzzer, das Funkmodul und das CAN-Modul betreffen, bleiben erhalten. Bei jedem anderen Wert startet das Modul mit der kompletten Default-Konfiguration, also derjenigen, wie sie unmittelbar nach der Auslieferung vorhanden war.

### 3.4 Externe Beschaltung

Die Ein- und Ausgänge der Control Unit können mit unterschiedlichen externen Beschaltungen versehen werden. Hierzu gehören z. B. Dimmer- oder Relaisstufen. Je nach Ausführung sind bereits einige Beschaltungen auf der Platine der Control Unit integriert, wie z. B. das TWI (Two Wire Interface) oder das SPI (Serial Peripheral Interface), welches zur Ansteuerung des CAN-Bus (Controller Area Network Bus) verwendet wird.

Welche Beschaltung eines Ein- bzw. Ausgangs vorgenommen wurde, muss der Software über Konfigurationsbefehle mitgeteilt werden. Die auf der Platine bereits vorhandenen Beschaltungen sind bereits vorkonfiguriert, sofern die dazu nötigen Software-Komponenten installiert wurden. Dadurch weist ein nicht konfiguriertes Modul bereits eine gewisse Basisfunktionalität auf, die die Inbetriebnahme erheblich erleichtert.

Ein solcher Konfigurationsbefehl hat die allgemeine Form:

VLAN Source Dest 64 Pin Value0 Value1 0

Pin spezifiziert den zu konfigurierenden Pin des Mikrocontrollers (A0 = 0 bis D7 = 31). Dann gibt Value0 (Code + Offset) den Typ der externen Beschaltung gemäß nachstehender Tabelle und Value1 die Geräte-Adresse des angeschlossenen Geräts an.

- 27 -

Code | Offset | Geräte-Typ | Voreinstell.
Pin | Adr.
0 | 0 | Statische Ausgabe (Pegel Low) | s. u. | s. u.
| 1 | Statische Ausgabe (Pegel High)
2 | 0 | Buzzer | B0 | 8
3 | 0 | Infrarot-Empfänger | D4 | 28
4 | 0 | Serielle Schnittstelle (Receiver) | D0 | 24
| 1 | Serielle Schnittstelle (Transmitter) | D1 | 25
6 | 0 | Nulldurchgangserkenn. Netzspannung/Ext. Reset | D2 | 26
8 | 0 | Serial Peripheral Interface (Slave Select) | B4 | 12
9 | 0 | Serial Peripheral Interface (Master Out - Slave In) | B5 | 13
10 | 0 | Serial Peripheral Interface (Master In - Slave Out) | B6 | 14
11 | 0 | Serial Peripheral Interface (System Clock) | B7 | 15
12 | 0 | Two Wire Interface (System Clock) | C0 | 16
13 | 0 | Two Wire Interface (System Data) | C1 | 17
16 | 0 | Geschaltetes Gerät
32 | 0 | Analoger Eingang
40 | 0 | Digitaler Eingang
48 | 0 | LCD (Display Data 0)
| 1 | LCD (Display Data 1)
| 2 | LCD (Display Data 2)
| 3 | LCD (Display Data 3)
| 4 | LCD (Display Data 4)
| 5 | LCD (Display Data 5)
| 6 | LCD (Display Data 6)
| 7 | LCD (Display Data 7)
| 8 | LCD (Read/Write)
| 9 | LCD (Register Select)
| 10 | LCD (Enable)
| 11 | LCD (Hintergrundbeleuchtung)
64 | 0 | Dimmer
| 1 | Dimmer und Soft-Delay
| 2 | Dimmer und Lange Zündimpulse
| 4 | Dimmer und Schaltrestriktion
| 8 | Dimmer und Phasenabschnittsteuerung
128 | 0 | Logischer Eingang
- 28 -

1 | Logischer Eingang und Steigende Flanke
2 | Logischer Eingang und Fallende Flanke
4 | Logischer Eingang und Prellfreiheit
8 | Logischer Eingang und Kurze Aktivierung
12 | Logischer Eingang und Lange Aktivierung
16 | Logischer Eingang und Pull-up Widerstand
32 | Logischer Eingang und Prellfreiheit erzwingen

Tabelle 3.1: Konfiguration der Geräte-Typen

Alle Pins, die in obiger Tabelle in der Spalte Voreinstellung nicht aufgeführt sind, werden standardmäßig als Statische Ausgabe (Pegel Low) konfiguriert und bekommen die Geräte-Adresse, die der Nummer des Pins entspricht (A0 = 0 bis D7 = 31).

Addiert man zu dem zu konfigurierenden Pin 32, so gibt Value0 die Moduladresse an, an die das an dem entsprechenden Pin konfigurierte Gerät seine Statusmeldungen verschickt. Die Voreinstellung ist hier 0, was das Versenden jeglicher Statusmeldungen unterbindet. Entspricht die Adresse der Moduladresse des Moduls, auf dem das Gerät konfiguriert ist, wird die Statusmeldung nur lokal verarbeitet und nicht versendet. Soll eine Statusmeldung lediglich von der Central Control Unit verarbeitet werden, so wird deren Adresse hier eingesetzt. Analoges gilt für jede andere Control Unit. Broadcasts und Multicasts können hier in gewohnter Weise verwendet werden.

### 3.5 Zeitsynchronisation

In einigen Komponenten der Control Unit ist es erforderlich, die aktuelle Tageszeit inklusive Wochentag verfügbar zu haben, um verschiedene Steueraufgaben adäquat durchführen zu können. Aus diesem Grund ist in die Control Unit eine vollständige Uhr integriert worden. Zum Einstellen der Uhrzeit kann der folgende Befehl verwendet werden:

VLAN Source Dest 120 Hundredth Second Minute HourDay

HourDay spezifiziert dabei den aktuellen Wochentag – die niederwertigen drei Bits beginnend mit Montag=0 – und die momentane Stunde – die höherwertigen fünf Bits.

- 29 -

Minute steht dann für die aktuell vergangenen Minuten, Second für die Sekunden und Hundredth für die hundertstel Sekunden. Die Voreinstellung ist bei allen Werten 0.

Nach jedem Neustart oder Reset versendet die Control Unit eine so genannte Synchronisationsanfrage der folgenden Form:

VLAN Source Dest 123 0 0 0 0

Erreicht diese Anfrage einen so genannten Time-Server, so antwortet dieser mit einer Nachricht zum Einstellen der Uhrzeit, so wie es am Anfang des Kapitels beschrieben ist.

Eine Control Unit kann gleichzeitig auch ein Time-Server sein. Dies lässt sich mit dem Befehl

VLAN Source Dest 76 7 TimeServer 0 0

festlegen. Ist TimeServer=0 ist die Control Unit kein Time-Server. Ist TimeServer=1 übernimmt das Modul die Funktion eines Time-Servers. Die Voreinstellung ist 0.

### 3.6 Software-Management

Da auch die Firmware der Control Unit einem ständigen Entwicklungsprozess unterliegt, existieren eine ganze Reihe unterschiedlicher Versionen. Um nun herauszufinden welche Firmware Version gerade auf einer Control Unit installiert ist, kann man dieser die Nachricht

VLAN Source Dest 76 28 0 0 0

schicken. In dem entsprechenden Antwortpaket wird dann als Value0 die Major-Nummer, als Value1 die Minor-Nummer und als Value2 die Phase der Version zurückgesendet.

Ferner besteht die Firmware aus verschiedenen Komponenten, die die Ansteuerung unterschiedlicher externer Beschaltungen bzw. Bauteile übernehmen oder sonstige Features zur Verfügung stellen. Schickt man einer Control Unit den Befehl

VLAN Source Dest 76 30 X 0 0

- 30 -so sendet die Unit im Antwortpaket als Value1 das X-te Byte der Eigenschaft, die die in der Firmware enthaltenen Komponenten spezifiziert. Diese Eigenschaft besteht aus vier Byte, wobei vom niederwertigsten mit 0 begonnen wird zu zählen. Die Bedeutung der einzelnen Bits dieser Eigenschaft kann folgender Tabelle entnommen werden. Dabei ist die entsprechende Komponente vorhanden, wenn das zugehörige Bit gesetzt ist.
Bit | Komponente
0 | EEPROM-Support
1 | Externer Reset
2 | Buzzer
3 | Funkmodul
4 | CAN-Bus
5 | Infrarotschnittstelle
6-7 | 2 – LCD-Display (2 x 16 Zeichen) 3 – LCD-Display (3 x 16 Zeichen)
8 | Logische Eingänge
9 | Analoge Eingänge
10 | Dallas Digitales Thermometer
11 | Schalter
12 | Dimmer
13 | Rollladensteuerung
14-15 | 1 – Drehgeber (PEC11) 2 – Drehgeber (STEC)
16 | Bedienoberfläche
17 | Autonome Steuerung
18-31 | Nicht verwendet

Tabelle 3.2: Softwarekomponenten

Im Folgenden ist mit Firmware stets die compilierte Version ohne zusätzliche Informationen, wie Adressen oder ähnliches, also der reine Byte-Code gemeint.

Möchte man eine neue Firmware Variante auf einer Control Unit installieren, so ist zunächst deren Größe zu spezifizieren. Dies geschieht mit dem Befehl

VLAN Source Dest 76 27 LByte HByte 0

wobei LByte und HByte einen 16-Bit Wert bilden, der die Größe der Firmware in Byte

- 31 -angibt. Jetzt kann mit dem Befehl

VLAN Source Dest 56 0 16 0 0

der Firmware Download eingeleitet werden. Dieser Download erfolgt nun seitenbasiert, das heißt, es werden immer ganze Seiten von 64 Byte Größe übertragen und die Anzahl der übertragenen Seiten muss gerade sein. Eine nicht vollständig gefüllte Seite bzw. – siehe obige Bedingung nach gerader Seitenanzahl – eine völlig leere Seite wird mit 0xFF aufgefüllt. Die Firmware wird dadurch auf eine Größe gebracht, die durch 128 teilbar ist. Obige Spezifikation der Firmware Größe bezieht sich wohl gemerkt auf die tatsächliche Größe, also ohne die Füllbytes. Die Reihenfolge, in der die Seiten übertragen werden, ist prinzipiell egal. Eine Seite kann
auch | mehrfach | übertragen | werden, | wenn | z. | B. | beim | vorherigen
Übertragungsversuch ein Fehler aufgetreten ist. Um nun eine einzelne Seite zu downloaden wird zunächst ein Startpaket geschickt:

VLAN Source Dest 56 16 160 LSideAddr HSideAddr

LSideAddr und HSideAddr bilden dabei einen 16-Bit Wert, der die Startadresse der Seite in Byte angibt. Die erste Seite hat die Adresse 0x0000, die zweite Seite die Adresse 0x0040 usw.. Jetzt folgen 16 Datenpakete – 16 Pakete x 4 Byte = 64 Byte = 1 Seite – in der Form

VLAN Source Dest 60 Data0 Data1 Data2 Data3
VLAN Source Dest 60 Data4 Data5 Data6 Data7
VLAN Source Dest 60 Data8 Data9 Data10 Data11 usw.

Um die Übertragung einer Seite abzuschließen, folgt ein Paket mit Prüfsummen:

VLAN Source Dest 60 Checksum0 Checksum1 Checksum2 Checksum3

Sind die Prüfsummen korrekt wird dieses Paket mit einem Acknowledge beantwortet, ansonsten mit einem Error. Das Startpaket und die Datenpakete erhalten jeweils keine Bestätigung. Nun kann die nächste Seite übertragen werden oder aber die vorherige noch einmal, sollte das Prüfsummenpaket mit einem Fehler oder gar nicht bestätigt werden.

Die Prüfsummen werden über die Daten-Bytes gebildet, also über Device und Value0 bis Value2 und zwar so, dass die Summe aller vorherigen 16 Datenpakete plus das

- 32 -

Seitenstartpaket plus das Prüfsummenpaket modulo 256 Null ergibt. In Device werden also die Device-Werte summiert, in Value0 die Value0-Werte usw.. Dabei wird das Startpaket, die 16 Datenpakete und das Prüfsummenpaket mit einbezogen.

Abgeschlossen wird der Firmware-Download mit einem Download-Ende-Paket:

VLAN Source Dest 56 1 0 0 0

Diese Prozedur hat die Konfiguration der Control Unit verändert. Soll diese nach einem Reset erhalten bleiben – das ist für einen erfolgreichen Installationsvorgang unbedingt erforderlich –, muss sie zunächst gespeichert werden (siehe Kapitel 3.3 Konfigurationsmanagement).

Die neue Firmware befindet sich jetzt in einem externen EEPROM und muss noch in den Flash-Speicher des Mikrocontrollers übertragen werden. Dieser Zustand, also ob eine neue Firmware zur Übertragung in den Flash im EEPROM zur Verfügung steht, kann mit dem Befehl

VLAN Source Dest 76 24 0 0 0

erfragt werden. In dem entsprechenden Antwortpaket nimmt Value0 den Wert 0 an, wenn dem so ist und den Wert 255 im anderen Fall.

Nach dem Speichern der Konfiguration muss die Control Unit neu gestartet werden, es muss also ein so genannter Full-Reset durchgeführt werden (siehe Kapitel 3.2 Resets und Neustarts). Beim Neustart erkennt der Bootloader, dass eine neue Firware zum Flashen im EEPROM zur Verfügung steht und führt den Flash-Vorgang durch. Dies kann je nach Größe der Firmware einige Zeit in Anspruch nehmen. Danach wird automatisch die neue Firmware zur Ausführung gebracht, was durch den charakteristischen Piep-Ton bzw. das Aufleuchten der Control-LED signalisiert wird.

- 33 -

## 4 Komponenten

Die Firmware der Control Unit besteht aus unterschiedlichen Komponenten oder Modulen, die für die Ansteuerung unterschiedlicher externer Beschaltungen bzw. für bestimmte Software-Features benötigt werden (siehe Kapitel 3.6 Software-Management). Im Allgemeinen sind nie alle Komponenten in einer Firmware enthalten. Dieses Kapitel beschreibt die unterschiedlichen Komponenten und erklärt deren Einsatzmöglichkeiten.

### 4.1 EEPROM-Support

Zusätzlich zu dem im Mikrocontroller enthaltenen EEPROM verfügt eine Control Unit über zwei externe EEPROMs, die zusätzlichen Speicherplatz bereitstellen. Dieser wird unter anderem für die Installation neuer Firmware (siehe Kapitel 3.6 Software-Management) und für die Speicherung der Konfigurationsdaten der Bedienoberfläche (siehe Kapitel 4.16 Bedienoberfläche) genutzt. Die beiden EEPROMs haben eine Größe von 32 KByte bzw. 8 KByte. Die Komponente EEPROM-Support stellt die
Möglichkeit | bereit, | die Inhalte | der EEPROMs | über die | verfügbaren
Kommunikationsschnittstellen auszulesen.

Hierzu wird einer Control Unit folgende Nachricht gesendet:

VLAN Source Dest 28 EEPROMReadAddr LAddr HAddr Number

EEPROMReadAddr ist die Lese-Adresse des EEPROMs, welches ausgelesen werden soll. Das 32 KByte EEPROM hat die Lese-Adresse 161 und das 8 KByte EEPROM die Lese-Adresse 169. LAddr und HAddr bilden zusammen einen 16-Bit Wert, der die Adresse innerhalb des EEPROMs angibt, ab der gelesen werden soll. Diese Adresse ist Byte-basiert und beginnt bei 0. Number gibt schließlich die Anzahl Bytes an, die ausgelesen werden soll. Mit einem Lesebefehl können höchstens 64 Byte ausgelesen werden.

Die Control Unit schickt daraufhin die angeforderten Daten an den Sender in folgender Form zurück:

VLAN Source Dest 29 Data0 Data1 Data2 Data3
VLAN Source Dest 29 Data4 Data5 Data6 Data7
VLAN Source Dest 29 Data8 Data9 Data10 Data11 usw.
- 34 -

Es werden dabei so viele Pakete geschickt, wie nötig sind, um die angeforderten Bytes zu übermitteln. Abschließend wird das anfragende Paket noch einmal bestätigt oder es wird mit einem Fehler quittiert, wenn es nicht korrekt verarbeitet werden konnte.

### 4.2 Externer Reset

Je nach Ausführung der Hardware einer Control Unit ist auf der Platine ein Taster oder zwei Pins zum Setzen einer Brücke untergebracht, mit deren Hilfe ein Reset der Control Unit von Extern herbeigeführt werden kann. Gegebenenfalls kann ein zusätzlicher Taster am Modulgehäuse angebracht werden, der über die gegebenen Steckverbindungen angeschlossen werden kann.

Wird dieser Taster für mindestens eine Sekunde betätigt, führt die Control Unit einen Konfigurationsreset durch (siehe Kapitel 3.2 Resets und Neustarts). Dieser wird von einem Signalton bzw. dem Aufleuchten der Control-LED der Stärke „Panic“ begleitet. So besteht die Möglichkeit, die Control Unit händisch in den Auslieferungszustand zu versetzen, falls eine Kommunikation mit der Control Unit bzw. ein Ändern der Konfiguration nicht mehr möglich ist.

### 4.3 Buzzer

In den meisten Fällen ist an einer Control Unit eine akustische – in Form eines Buzzers – oder optische – in Form einer Control-LED – Signaleinrichtung angebracht. Diese dient neben der Signalisierung von bestimmten Systemzuständen vor allem der Unterstützung des Anwenders bei der Benutzung der Infrarot-Fernbedienung und der Bedienoberfläche, sowie als Rückmeldung nach erfolgreichem oder aber fehlgeschlagenen Ansteuern eines Geräts.

Es werden drei verschiedene Signalstärken unterschieden, die sich nur hinsichtlich ihrer Länge unterscheiden:

Signal | Dauer
Ack | 1/10 s
Error | 1 s
Panic | 4,5 s

Tabelle 4.1: Signalarten

- 35 -

Welches Signal an welcher Stelle eingesetzt wird, ist in den entsprechenden Kapiteln beschrieben.

Ob in einer gegebenen Situation ein Signal gegeben wird ist vom jeweiligen Buzzerlevel abhängig. Dieser kann wie folgt konfiguriert werden:

VLAN Source Dest 76 16 LByte HByte 0

Dabei bilden LByte und HByte einen 16-Bit Wert, der den Buzzerlevel spezifiziert. Der Vorgabewert ist 0xFFFF. Jedes gesetzte Bit in diesem Wert sorgt für das Auslösen des Signals in der entsprechenden Situation gemäß folgender Tabelle:

Bit | Bedeutung
0 | Systemmeldung
1
2
3
4 | IR-Tastendruck
5 | IR-Befehlsbestätigung
6 | IR-Fehler
7 | IR-Lernbestätigung
8 | GUI-Tastendruck
9 | GUI-Befehlsbestätigung
10 | GUI-Fehler
11 | GUI-Drehereignis
12
13
14
15

Tabelle 4.2: Buzzerlevel

Die Bedeutung der einzelnen Bits soll im Folgenden noch näher erläutert werden:

- Systemmeldung
Hierzu zählen alle Ereignisse, die durch das System im Laufe des Betriebs selbst hervorgebracht werden, wie z. B. Neustart oder Systemfehler.
- 36 -

- IR-Tastendruck
Ein Signal wird gegeben, wenn auf einer Fernbedienung eine Taste gedrückt wurde.
- IR-Befehlsbestätigung
Ein über eine Fernbedienung abgesetzter Befehl wird bestätigt, sofern dieser erfolgreich ausgeführt werden konnte.
- IR-Fehler
Ein Fehler wird signalisiert, wenn ein über eine Fernbedienung abgesetzter Befehl nicht erfolgreich verarbeitet werden konnte.
- IR-Lernbestätigung
Das erfolgreiche Lernen eines Tastencodes einer Fernbedienung wird signalisiert.
- GUI-Tastendruck
Ein Signal wird gegeben, wenn in Verbindung mit der Bedienoberfläche eine Taste gedrückt wird.
- GUI-Befehlsbestätigung
Ein über die Bedienoberfläche abgesetzter Befehl wird bestätigt, sofern dieser erfolgreich ausgeführt werden konnte.
- GUI-Fehler
Ein Fehler wird signalisiert, wenn ein über die Bedienoberfläche abgesetzter Befehl nicht erfolgreich verarbeitet werden konnte.

### 4.4 Funkmodul

Eine mögliche Schnittstelle zur Kommunikation mit anderen Control Units bzw. mit der Central Control Unit stellt die Beschaltung mit einem Funkmodul dar. Dieses wird an die serielle Schnittstelle der Control Unit angeschlossen. Prinzipiell ist es auch möglich, statt Funk ein beliebiges anderes Übertragungsmedium – z. B. ein Kabel – zu benutzen. Ursprünglich wurde diese Komponente jedoch als Funkmodul konzipiert. Über diese Schnittstelle können dann die Nachrichten versendet werden, wie sie in diesem Dokument beschrieben werden.

- 37 -

Zunächst muss hierfür die entsprechende Pin-Konfiguration vorgenommen werden, wie sie in Kapitel 3.4 Externe Beschaltung beschrieben wurde. Anschließend wird die VLAN-ID für die Schnittstelle mit dem Befehl

VLAN Source Dest 76 12 VLAN-ID 0 0

festgelegt, wobei VLAN-ID eben diese ID angibt. Die Voreinstellung ist 0. Nun ist die Funk-Schnittstelle prinzipiell einsatzbereit.

Um die Sicherheit bei der Übertragung der Daten hinsichtlich des Abhörens und der gezielten Manipulation des Funkverkehrs zu erhöhen, besteht die Möglichkeit, die übertragenen Daten zu verschlüsseln. Ob der Funkverkehr verschlüsselt werden soll, kann über folgenden Befehl konfiguriert werden:

VLAN Source Dest 76 14 Mode 0 0

Ist Mode gleich 0, findet keine Verschlüsselung statt, ist Mode gleich 1, wird die gesamte Nachricht bis auf die VLAN-ID verschlüsselt und ist Mode gleich 3, so wird die gesamte Nachricht inklusive der VLAN-ID verschlüsselt. Per Voreinstellung findet keine Verschlüsselung statt. Um die Daten nun sinnvoll zu verschlüsseln, muss ein acht Byte langer Schlüssel – per Voreinstellung sind alle Bytes des Schlüssels mit 0 initialisiert – auf der Control Unit hinterlegt werden. Hierbei wird jedes Byte einzeln mit dem Befehl

VLAN Source Dest 76 15 Number Value 0

festgelegt, wobei Number die Nummer (0 bis 7) des festzulegenden Bytes angibt und Value das entsprechende Byte des Schlüssels repräsentiert. Es empfiehlt sich, zuerst den Schlüssel festzulegen und dann erst die Verschlüsselung einzuschalten, damit es in der Zwischenzeit nicht zu Kommunikationsproblemen kommt. Verschlüsselt bzw. entschlüsselt wird, in dem jedes einzelne Byte einer Nachricht mit dem entsprechenden Byte des Schlüssels „Exklusiv Oder“ verknüpft wird.

Liegen zwei Control Units soweit auseinander, dass die Sendeleistung des Funkmoduls nicht ausreicht, die Distanz zu überbrücken, lässt sich dazwischen eine Art „Funk-Hub“ installieren um die Distanzen zu verringern. Eine solche Control Unit leitet dann alle Nachrichten, die von entsprechend konfigurierten Control Units empfangen werden bzw. für diese bestimmt sind weiter. Sie tritt damit in gewisser

- 38 -

Weise als Stellvertreter für diese entfernten Control Units auf. Eine Control Unit kann als „Funk-Hub“ für bis zu vier andere Control Units fungieren, wobei lediglich die Moduladressen der entfernten Control Units auf der Control Unit, die als „Funk-Hub“ arbeitet, konfiguriert werden müssen. Dies geschieht mit folgendem Befehl:

VLAN Source Dest 76 11 Number Address 0

Number ist die Nummer (0 bis 3) der entfernten Control Unit und Address deren Moduladresse. Ist Address gleich 0 – das ist die Voreinstellung – dann ist diese Funktion deaktiviert. Ansonsten sind bei der Angabe der Moduladresse die Konventionen einzuhalten, wie sie im Kapitel 3.1.2 Modul-Adressierung beschrieben sind.

### 4.5 CAN-Bus

Eine weitere mögliche Schnittstelle zur Kommunikation mit anderen Control Units ist der CAN-Bus (Controller Area Network Bus). Hierbei ist der Anschluss eines entsprechenden CAN-Bus Controllers an das SPI (Serial Peripheral Interface) der Control Unit nötig, der damit die Verbindung zwischen der Control Unit und dem eigentlichen Bus bildet. Über diesen Bus können dann die üblichen Nachrichten verschickt werden.

Zur Konfiguration der CAN-Bus Schnittstelle muss die Pin-Konfiguration des SPI gemäß Kapitel 3.4 Externe Beschaltung vorgenommen werden. Weiter ist lediglich die VLAN-ID der Schnittstelle mit folgendem Befehl zu konfigurieren:

VLAN Source Dest 76 18 VLAN-ID 0 0

VLAN-ID gibt dabei eben diese ID an. Die Voreinstellung ist 0. Damit ist die Konfiguration der CAN-Bus Schnittstelle abgeschlossen und diese betriebsbereit.

### 4.6 Infrarotschnittstelle

Die Software bietet die Möglichkeit des Betriebs einer Infrarotschnittstelle. Nimmt man eine adäquate Beschaltung der Control Unit mit einem Infrarotempfänger vor, so kann man daran eine handelsübliche Fernbedienung betreiben und darüber Steuerbefehle für die gesamte HA-Umgebung absetzen.

- 39 -

Zur Pin-Konfiguration des Infrarotempfängers ist gemäß Kapitel 3.4 Externe Beschaltung vorzugehen.

### 4.6.1 Konfiguration der Fernbedienung

Eine Grundvoraussetzung, die die Fernbedienung erfüllen muss, ist, dass sie mit dem RC5-Code arbeitet. Dies ist bei den meisten Fernbedienungen der Fall. Ferner muss die Control Unit auf die daran zu betreibende Fernbedienung abgestimmt werden. So hat jede Fernbedienung eine Geräteadresse, die bei jedem Tastendruck mitgesendet wird. Diese ist, und sollte es auch, von Fernbedienung zu Fernbedienung unterschiedlich. Die Control Unit reagiert nur auf die Fernbedienung, dessen Geräteadresse mit der zuvor konfigurierten übereinstimmt. Damit wird verhindert, dass z. B. bei der Fernbedienung des Fernsehers die Control Unit mit angesprochen wird. Darüber hinaus sind die Tastencodes, die bei Betätigung einer Taste versendet werden nicht immer bei jeder Fernbedienung gleich. Darum ist es wichtig, auf der Control Unit eine Zuordnung der Tasten-Codes zu den entsprechenden Kommandos, die durch den Tastendruck ausgelöst werden sollen, vorzunehmen.

Die Abstimmung einer Control Unit auf eine entsprechende Fernbedienung wird mit folgendem Konfigurationsbefehl vorgenommen:

VLAN Source Dest 80 Button Command Device 0

Button ist hierbei der Tastencode einer bestimmten Taste, Command der Code des Kommandos, das durch den Tastendruck gegeben werden soll gemäß unten stehender Tabelle und Device die Geräteadresse der Fernbedienung.

- 40 -

Code | Kommando
0 | Taste 0
1 | Taste 1
2 | Taste 2
3 | Taste 3
4 | Taste 4
5 | Taste 5
6 | Taste 6
7 | Taste 7
8 | Taste 8
9 | Taste 9
12 | Alles Einschalten
15 | Alles Ausschalten
30 | Makro
32 | Plus
33 | Minus
38 | Enter
62 | Ignorieren

Tabelle 4.3: IR-Kommandos

Jeder Taste bzw. jedem Tastencode ist nun entsprechend ein Kommando zuzuordnen. Soll eine Taste keine Funktion haben, so ordnet man ihr den Kommandocode 62 zu. Die Control Unit wird diese Taste dann ignorieren. Per Voreinstellung ist jedem möglichen Tastencode von 0 bis 63 der identische Kommandocode zugeordnet. Die Geräteadresse ist 0.

Da es sehr schwierig ist, die Geräteadresse und die Tastencodes einer Fernbedienung zu ermitteln, gibt es eine elegantere Möglichkeit obige Zuordnung vorzunehmen. Man gibt ein Kommando vor und ordnet den Tastencode zu, indem man die entsprechende Taste auf der Fernbedienung drückt. Die Control Unit lernt dann gewissermaßen die Codes und auch die Geräteadresse von der Fernbedienung.

Um nun einen solchen Lernvorgang einzuleiten, schickt man der Control Unit den Befehl

- 41 -

VLAN Source Dest 84 0 Command 0 0

Command ist auch hier wieder der Code des zuzuordnenden Kommandos (siehe obige Tabelle). Dieser Befehl wird erst einmal nicht im herkömmlichen Sinn von der Control Unit beantwortet. Wird nun innerhalb der nächsten 4 Sekunden eine Taste auf der Fernbedienung betätigt und von der Control Unit registriert, wird die mit dem Tastendruck übermittelte Geräteadresse gespeichert und der übermittelte Tastencode dem zuvor definierten Kommando zugeordnet. Die Signaleinrichtung bestätigt dies mit einem Ack und die Control Unit beantwortet den ursprünglichen Befehl in der Form

VLAN Source Dest 85 Button Command Device 0

wobei Button wieder der Tastencode, Command der Code des festgelegten Kommandos und Device die Geräteadresse der Fernbedienung ist. Konnte die Control Unit innerhalb der 4 Sekunden kein Signal von einer Fernbedienung empfangen, schickt sie folgende Fehlernachricht:

VLAN Source Dest 86 0 Command 0 0

Dabei ist Command wieder der Code des Kommandos, welches festgelegt werden sollte. Die Signaleinrichtung quittiert diesen Zustand mit einem Error.

### 4.6.2 Infrarot-Adressen und Hot-Keys

Um ein Gerät ansteuern zu können, muss die Modul-Adresse der Control Unit, an der das Gerät angeschlossen ist und die Geräte-Adresse selbst bekannt sein. Da eine Modul-Adresse als auch eine Geräte-Adresse aus jeweils drei Ziffern besteht, wäre die Eingabe eines sechs stelligen Codes über die Fernbedienung nötig, um das zu steuernde Gerät eindeutig zu spezifizieren. Da dies einem Anwender nicht zuzumuten ist, lassen sich pro Infrarotschnittstelle 100 zwei stellige Codes (auch Infrarot-Adressen genannt) definieren, hinter denen sich jeweils wieder eine Modul-und eine Geräte-Adresse verbirgt, die an Stelle der sechs stelligen Codes benutzt werden.

Eine Geräte-Adresse und die zugehörige Modul-Adresse lassen sich einer Infrarot-Adresse wie folgt zuweisen:

- 42 -

VLAN Source Dest 68 IR Modul Device 0

IR ist dabei die Infrarot-Adresse, Modul die Modul-Adresse und Device die Geräte-Adresse. Per Voreinstellung wird jeder möglichen Infrarot-Adresse die Modul- und Geräte-Adresse 0 zugeordnet.

Ferner lassen sich 10 Hot-Keys definieren, die den 10 Ziffern der Fernbedienung entsprechen (siehe hierzu Kapitel 4.6.3 Bedienung). Einem Hot-Key wird eine Makro-Nummer zugeordnet und bei Betätigen dieses Hot-Keys wird ein Makro mit eben dieser Nummer generiert. Die Zuordnung findet über folgenden Befehl statt:

VLAN Source Dest 72 HotKey LMakro HMakro 0

HotKey ist die Nummer des Hot-Keys (0 bis 9) und LMakro und HMakro bilden zusammen einen 16-Bit Wert, der die Nummer des zugeordneten Makros repräsentiert. Allen Hot-Keys ist per Voreinstellung die Makro-Nummer 0 zugeordnet.

### 4.6.3 Bedienung

Grundsätzlich gilt, dass wenn ein Befehl nicht binnen 8 Sekunden über die Fernbedienung eingegeben wird, die Control Unit die Befehlseingabe abbricht und auf eine neue Eingabe wartet.

Bei den folgenden Darstellungen der Infrarot-Befehle steht jeder Ausdruck für jeweils ein über die Fernbedienung eingegebenes Kommando (siehe Kapitel 4.6.1 Konfiguration der Fernbedienung).

Die kürzesten Befehle, die eingegeben werden können, bestehen aus nur einem Kommando:

Command

Bei Command kann es sich um das Kommando Plus oder Minus handeln, was dazu führt, dass dem zuletzt über die Fernbedienung angesteuerten Gerät die Nachricht Plus bzw. Minus geschickt wird, was z. B. einen Dimmer dazu veranlasst seine Helligkeit etwas zu steigern bzw. zu verringern. Werden diese Tasten dauerhaft gedrückt, so wird das entsprechende Kommando periodisch wiederholt, bis die Taste wieder losgelassen wird.

- 43 -

Über den Befehl

Hot-Key Enter

wird ein Makro mit der Nummer generiert, die dem entsprechenden Hot-Key zugeordnet wurde (siehe Kapitel 4.6.2 Infrarot-Adressen und Hot-Keys). Hot-Key kann dabei das Kommando 0 bis 9 sein.

Um ein Makro ganz allgemeiner Form zu generieren, können folgende Befehlsformen verwendet werden:

Makro Number0 Enter

Makro Number1 Number0 Enter

Makro Number2 Number1 Number0 Enter

Makro Number3 Number2 Number1 Number0 Enter

Die Makro-Nummer wird durch NumberX spezifiziert, wobei X die Stelle bzw. die Wertigkeit der Nummer im Zehnersystem ist. Number kann dabei das Kommando 0 bis 9 sein.

Hat ein Befehl die Form

IR1 IR0 Enter

so wird der Status des Geräts, das durch die Infrarot-Adresse IR gegeben ist invertiert.

Wird ein Befehl in der Form

IR1 IR0 Value Enter

eingegeben, so wird dem Gerät, das durch die Infrarot-Adresse IR gegeben ist, der Wert (Value + 1) * 10 zugewiesen, es sei denn, Value ist das Kommando 0, dann ist der zugewiesene Wert ebenfalls 0.

Um den Wert, der dem anzusteuernden Gerät zugewiesen werden soll, in nativer Form anzugeben, wird der Befehl wie folgt verwendet:

IR1 IR0 Value2 Value1 Value0 Enter

- 44 -

IR ist wieder die Infrarot-Adresse des zu steuernden Geräts und Value der zuzuweisende Wert.

Möchte man auch noch die Zeit spezifizieren, innerhalb derer das anzusteuernde Gerät den neuen Wert annehmen soll, ist folgender Befehl zu verwenden:

IR1 IR0 Value2 Value1 Value0 Time1 Time0 Enter

IR ist auch hier wieder die Infrarot-Adresse des zu steuernden Geräts, Value der zuzuweisende Wert und Time die Zeit in Sekunden innerhalb derer das anzusteuernde Gerät den spezifizierten Wert anzunehmen hat.

Eine Fehleingabe wird durch die Signaleinrichtung mit einem Error quittiert, eine erfolgreiche Eingabe eines Befehls analog mit einem Ack. Jedes Drücken einer Taste wird zusätzlich mit einem Ack bestätigt. Dies alles gilt natürlich nur dann, wenn der Buzzerlevel entsprechend konfiguriert wurde (siehe Kapitel 4.3 Buzzer).

### 4.7 LCD-Display

Die Software einer Control Unit bietet die Möglichkeit zur Ansteuerung eines LCD (Liquid Crystal Display). Voraussetzung hierfür ist, dass das LCD über einen ST7036 Controller angesteuert wird, wie es z. B. bei den LCDs der DOG-Serie
standardmäßig | der | Fall | ist. | Im | Wesentlichen | wird | das | LCD | zu
Visualisierungszwecken im Zusammenhang mit der Bedienoberfläche verwendet (siehe Kapitel 4.16 Bedienoberfläche). Prinzipiell kann das LCD aber von jeder Komponente angesteuert werden. Insbesondere lässt es sich über spezielle Nachrichten steuern, die an die Control Unit, an die das LCD angeschlossen ist, geschickt werden.

Es werden unterschiedliche Display-Typen unterstützt, was durch die installierte Software sichergestellt werden muss (siehe hierzu Kapitel 3.6 Software-Management).

Die Pin-Konfiguration ist gemäß Kapitel 3.4 Externe Beschaltung vorzunehmen, wobei einige Besonderheiten zu berücksichtigen sind:

- Es werden nur die Datenpins 0 bis 3 verwendet, wobei diese auf einem Port und hintereinander liegen müssen.
- 45 -

- Die Pins Read/Write und Register Select müssen ebenfalls auf einem Port und hintereinander liegen.
- Die Device-Adresse wird auf jedem Pin gleich gesetzt.

Zur Ansteuerung des LCD über die diversen Kommunikationsschnittstellen stehen zwei spezielle Nachrichtentypen zur Verfügung. Mit

VLAN Source Dest 88 Char0 Char1 Char2 Char3

können vier Zeichen (Char0 bis Char3) auf dem Display ausgegeben werden. Das Zeichen 160 (0xA0) wird ignoriert. Mit

VLAN Source Dest 91 Inst0 Inst1 Inst2 Inst3

lassen sich vier Instruktionen bzw. Steuercodes (Inst0 bis Inst3) an das Display senden, wobei die Instruktion 0 ignoriert wird. Ist Inst0 gleich 0, definiert Inst1 den Wert für die Hintergrundbeleuchtung. Ist der Wert 0 wird die Hintergrundbeleuchtung ausgeschaltet. Für jeden anderen Wert wird sie eingeschaltet. Die Antwortpakete bei diesem Nachrichtentyp (Ack/Error) entsprechen denen des vorigen Nachrichtentyps. Sie bilden somit hier eine Ausnahme. Nähere Informationen zu den Instruktionen bzw. Steuercodes sind der Dokumentation des LCD bzw. des ST7036 Controllers zu entnehmen.

### 4.8 Logische Eingänge

Logische Eingänge dienen der Erfassung von logischen Eingangssignalen, die also lediglich aus zwei unterscheidbaren Zuständen bestehen. Sie werden im Rahmen des HAP vorwiegend zur Erfassung von Schaltzuständen von Schaltern, Tastern oder Kontakten benutzt. Sie kommen aber auch als Eingänge für Drehgeber und für weitere Aufgaben, die der Erfassung logischer Signalpegel dienen, zum Einsatz.

Zur Pin-Konfiguration sei auf das Kapitel 3.4 Externe Beschaltung verwiesen. Wird die Option Pull-up Widerstand gewählt, so wird der interne Pull-up Widerstand aktiviert und in den meisten Fällen kann dann auf eine aufwändige externe Beschaltung verzichtet werden.

Der Pegel, der an einem Pin anliegt, der als logischer Eingang konfiguriert ist, wird alle 10 ms abgegriffen. Signalwechsel, die schneller stattfinden können also nicht

- 46 -

registriert werden.

Der Wert, den ein logischer Eingang annimmt, entspricht nicht unbedingt dem Pegel, der an dem entsprechenden Pin anliegt. Dies ist je nach Konfiguration unterschiedlich. Der Wert ist eher eine abstrakte Eigenschaft des logischen Eingangs, der seinen Status beschreibt und der noch durch die Information ergänzt wird, durch welches Ereignis er in diesen Status versetzt wurde.

Ein logischer Eingang arbeitet also ereignisorientiert. Ein Ereignis ist zunächst einmal die Änderung des an dem entsprechenden Pin anliegenden Pegel. Auf ein solches Ereignis wird nur reagiert, wenn die entsprechende Flanke bei der Pin-Konfiguration Berücksichtigung gefunden hat (siehe Kapitel 3.4 Externe Beschaltung). Zusätzlich kann bestimmt werden, dass der Pegel nach einem Wechsel eine bestimmte Zeit stabil bleiben muss. Hier wird in der Pin-Konfiguration zwischen Prellfreiheit, kurze und lange Aktivierung unterschieden. Ist die kurze Aktivierung konfiguriert, werden aber auch Ereignisse berücksichtigt, die lediglich der Prellfreiheit genügen. Ebenso werden bei der Konfiguration der langen Aktivierung auch Ereignisse der kurzen Aktivierung und der Prellfreiheit akzeptiert. Nur wenn diese konfigurierten Bedingungen erfüllt sind, wird ein Ereignis registriert und der Status bzw. der Wert des logischen Eingangs ändert sich. Dann wird auch eine Statusmeldung generiert, die eben diesen Wert enthält.

Dieser Wert ist ein 8-Bit Wert und wird im LValue der Statusmeldung bzw. der Abfrage untergebracht. Der HValue ist dabei 0. Ebenso ist Select bzw. Ext gleich 0 (siehe Kapitel 3.1.8 Abfragen und 3.1.9 Statusmeldungen). Bit 7 von LValue ist 0, wenn das Ereignis eine steigende und 1, wenn es eine fallende Flanke war. Bit 2 und 3 von LValue geben die Zeit, die der Pegel nach seiner Änderung stabil war, gemäß folgender Tabelle an:

Bit 3 | Bit 2 | Zeit
0 | 0 | Keine Zeitrestriktion
0 | 1 | Prellfreiheit
1 | 0 | Kurze Aktivierung
1 | 1 | Lange Aktivierung

Tabelle 4.4: Aktivierungscodes von logischen Eingängen

- 47 -

Die Werte entsprechen also dem Offset der Pin-Konfiguration.

Wird per Konfiguration die Prellfreiheit erzwungen, so wird für jede nicht konfigurierte Flanke dennoch ein Ereignis generiert, sofern die Prellfreiheit gegeben ist.

Den einzelnen Zeitrestriktionen können die entsprechenden Zeitspannen über folgenden Konfigurationsbefehl zugeordnet werden:

VLAN Source Dest 76 32 Code LTime HTime

Code ist der Code der Zeitrestriktion deren Zeitspanne festgelegt werden soll gemäß unten stehender Tabelle. LTime und HTime bilden zusammen einen 16-Bit Wert, der die festzulegende Zeitspanne in hundertstel Sekunden angibt. Die jeweilige Voreinstellung ist ebenfalls der Tabelle zu entnehmen.

Code | Zeitrestriktion | Voreinstellung
0 | Keine Zeitrestriktion | 0 s
1 | Prellfreiheit | 0,1 s
2 | Kurze Aktivierung | 0,5 s
3 | Lange Aktivierung | 1,5 s

Tabelle 4.5: Voreingestellte Aktivierungszeiten bei logischen Eingängen

### 4.9 Analoge Eingänge

Analoge Eingänge dienen der Messwerterfassung mit Hilfe analoger Sensoren. Darunter werden hier Sensoren verstanden, die über eine entsprechende externe Beschaltung an den in den Mikrocontroller der Control Unit integrierten Analog to Digital Converter angeschlossen werden können, der den analogen Messwert zur Weiterverarbeitung in einen digitalen verwandelt. Als Beispiel seien hier temperaturabhängige oder helligkeitsabhängige Widerstände genannt.

Über das reine Erfassen von Messwerten hinaus, können jedem analogen Eingang bis zu zwei Triggerpunkte zugewiesen werden, die bei Über- bzw. Unterschreiten – das ist von der jeweils aktuellen Konfiguration abhängig – Statusmeldungen generieren.

Zur Nutzung der analogen Eingänge ist die entsprechende Komponente der

- 48 -

Software zu aktivieren (siehe Kapitel 3.6 Software-Management).

Zur Pin-Konfiguration sei auf das Kapitel 3.4 Externe Beschaltung verwiesen. Hierbei ist zu beachten, dass die Sensoren ausschließlich an Port A angeschlossen werden können.

Wie oft ein Messwert vom Sensor abgefragt wird, wird durch die Sample-Rate definiert. Diese kann nicht höher sein, als zehn mal pro Sekunde. Konfiguriert wird sie über folgenden Befehl:

VLAN Source Dest 76 80 Addr LRate HRate

Addr ist dabei die Device-Adresse des analogen Eingangs – bei den folgenden Konfigurationsbefehlen ist das ebenfalls so – und LRate und HRate bilden zusammen einen 16-Bit Wert, der die Sample-Rate in Zehntelsekunden angibt. Die Voreinstellung ist 60 Sekunden.

Die Triggerpunkte und die zugehörige Hysterese sowie die Triggerflags werden mit dem Befehl

VLAN Source Dest 76 Code Addr LValue HValue

bzw.

VLAN Source Dest 76 Code Addr Hyst Flags

festgelegt. Ist Bit 0 von Code 0, wird der Triggerwert festgelegt, andernfalls die Hysterese und die Triggerflags. Bit 1-3 kodieren die Nummer des Triggers. Bit 4-7 sind 0010. Ist Code also 64 wird der Triggerwert des Triggers 0 festgelegt. Ist Code 65, legt man die Hysterese und die Triggerflags des Triggers 0 fest. LValue und HValue bilden zusammen einen 16-Bit Wert, der den Triggerwert repräsentiert. Hyst steht für die Hysterese und Flags für die Triggerflags. Der Triggerwert, die Hysterese und auch die Triggerflags werden per Voreinstellung auf 0 gesetzt.

Der Triggerwert weist dasselbe Format auf, wie der Wert des analogen Eingangs selbst. Dieses Format sei im Folgenden dargestellt:

LByte

Bit 7 | Bit 6 | Bit 5 | Bit 4 | Bit 3 | Bit 2 | Bit 1 | Bit 0
2 3 | 2 2 | 2 1 | 2 0 | 2 -1 | 2 -2 | 2 -3 | 2 -4
- 49 -

HByte

Bit 15 | Bit 14 | Bit 13 | Bit 12 | Bit 11 | Bit 10 | Bit 9 | Bit 8
2 11 | 2 10 | 2 9 | 2 8 | 2 7 | 2 6 | 2 5 | 2 4

Abb. 4.1: Allgemeines Werteformat bei analogen Eingängen

Die Hysterese besitzt das gleiche Format wie das LByte des Triggerwerts. Von den Triggerflags sind nur Bit 2 und Bit 3 relevant. Alle anderen Bits werden intern verwendet und sind bei der Konfiguration auf 0 zu setzen. Ist Bit 2 gesetzt, so wird der analoge Eingang eine Statusmeldung (siehe Kapitel 3.1.9 Statusmeldungen) generieren, sobald der aktuelle Messwert den Triggerwert unterschreitet. Eine weitere Statusmeldung folgt, wenn der Messwert mindestens wieder den Triggerwert plus Hysterese erreicht, nachdem der Triggerwert vorher unterschritten worden ist. Ist Bit 3 gesetzt, so generiert der analoge Eingang eine Statusmeldung, sobald der aktuelle Messwert den Triggerwert überschreitet. Eine weitere Statusmeldung folgt dann, wenn der Messwert mindestens wieder den Triggerwert minus Hysterese erreicht, nachdem der Triggerwert vorher überschritten worden ist. Sind diese Bits nicht gesetzt, bleiben die entsprechenden Statusmeldungen aus.

Die Statusmeldungen haben das Format, wie es in Kapitel 3.1.9 Statusmeldungen beschrieben ist. Während HValue und Ext 0 sind, codiert LValue den Trigger und das Ereignis, das zum Auslösen der Statusmeldung führte. Die Triggernummer des Triggers, der das Ereignis auslöste, wird in den Bits 0-2 codiert. Bit 3-5 sind immer 0. Bit 6 und Bit 7 codieren das Ereignis gemäß folgender Tabelle:

Bit 7 | Bit 6 | Ereignis
0 | 0 | Der Triggerwert plus Hysterese wurde wieder erreicht, nachdem er zuvor unterschritten wurde.
0 | 1 | Der Triggerwert wurde unterschritten.
1 | 0 | Der Triggerwert minus Hysterese wurde wieder erreicht, nachdem er zuvor überschritten wurde.
1 | 1 | Der Triggerwert wurde überschritten.

Tabelle 4.6: Ereigniscodierung bei analogen Eingängen

Soll der aktuelle Wert eines analogen Eingangs abgefragt werden (siehe Kapitel 3.1.8 Abfragen), so ist Select auf 0 zu setzen. Dann liefert LValue und HValue zusammen den 16-Bit Wert des Eingangs gemäß oben stehenden Formats. Hat

- 50 -

Select die Form 1010TT00 und wird für TT die Nummer eines Triggers eingesetzt, so liefert LValue und HValue zusammen den 16-Bit Wert des entsprechenden Triggers, ebenfalls gemäß oben stehenden Formats. Entspricht Select keinem dieser Muster, wird als Ergebnis 0xFFFF zurückgeliefert.

Die Triggerwerte lassen sich auch über gewöhnliche Steuerbefehle (siehe Kapitel 3.1.7 Steuerbefehle) setzen, indem Value auf 1010TT00, wobei TT für die Nummer des entsprechenden Triggers codiert, gesetzt wird. Dann bildet LParam und HParam zusammen den 16-Bit Wert, der dem Trigger zugewiesen wird.

Der integrierte Analog to Digital Converter hat eine Auflösung von 10 Bit. Davon codieren 8 Bits den Wert links vom Komma und 2 Bits stehen für den Wert rechts vom Komma. Das bedeutet, das die Bits 0-1 und 12-15 des Werts des analogen Eingangs, so wie weiter oben beschrieben, nicht verwendet werden. Diese Bits sind immer 0. Dies führt dann zu folgendem Format:

LByte

Bit 7 | Bit 6 | Bit 5 | Bit 4 | Bit 3 | Bit 2 | Bit 1 | Bit 0
2 3 | 2 2 | 2 1 | 2 0 | 2 -1 | 2 -2 | 0 | 0

HByte

Bit 15 | Bit 14 | Bit 13 | Bit 12 | Bit 11 | Bit 10 | Bit 9 | Bit 8
0 | 0 | 0 | 0 | 2 7 | 2 6 | 2 5 | 2 4

Abb. 4.2: Konkretes Werteformat bei analogen Eingängen

Die genaue Zuordnung der Spannungshöhen an den analogen Eingängen zu den
digitalisierten | Werten, | sowie | weitere | Informationen | über | externe
Beschaltungsmöglichkeiten, sind dem Datenblatt des verwendeten Mikrocontrollers zu entnehmen.

### 4.10 Digitale Eingänge

Digitale Eingänge dienen der Messwerterfassung mit Hilfe digitaler Sensoren. Unter digitalen Sensoren werden hier Sensoren verstanden, die über ein 1-Wire Interface verfügen, über welches der Messwert ausgelesen werden kann.

Über das reine Erfassen von Messwerten hinaus, können jedem digitalen Eingang

- 51 -bis zu zwei Triggerpunkte zugewiesen werden, die bei Über- bzw. Unterschreiten – das ist von der jeweils aktuellen Konfiguration abhängig – Statusmeldungen generieren.

Gegebenenfalls macht die Benutzung eines bestimmten Sensors die Aktivierung einer bestimmten Softwarekomponente nötig (siehe hierzu Kapitel 3.6 Software-Management).

Zur Pin-Konfiguration sei auf das Kapitel 3.4 Externe Beschaltung verwiesen. Hierbei ist zu beachten, dass die Sensoren ausschließlich an Port A und nur einer pro Pin angeschlossen werden können.

Wie oft ein Messwert vom Sensor abgefragt wird, wird durch die Sample-Rate definiert. Diese kann nicht höher sein, als einmal pro Sekunde. Konfiguriert wird sie über folgenden Befehl:

VLAN Source Dest 76 144 Addr LRate HRate

Addr ist dabei die Device-Adresse des digitalen Eingangs – bei den folgenden Konfigurationsbefehlen ist das ebenfalls so – und LRate und HRate bilden zusammen einen 16-Bit Wert, der die Sample-Rate in Sekunden angibt. Die Voreinstellung ist 60 Sekunden. Mit

VLAN Source Dest 76 145 Addr Type 0

wird der Sensortyp gemäß unten stehender Tabelle spezifiziert, wobei die Voreinstellung 0 ist.

Type | Sensortyp
1 | Dallas Digitales Thermometer DS18B20
2 | Dallas Digitales Thermometer DS18S20

Tabelle 4.7: Typen digitaler Sensoren

Die Triggerpunkte und die zugehörige Hysterese sowie die Triggerflags werden mit dem Befehl

VLAN Source Dest 76 Code Addr LValue HValue

bzw.

- 52 -

VLAN Source Dest 76 Code Addr Hyst Flags

festgelegt. Ist Bit 0 von Code 0, wird der Triggerwert festgelegt, andernfalls die Hysterese und die Triggerflags. Bit 1-3 kodieren die Nummer des Triggers. Bit 4-7 sind 0001. Ist Code also 128 wird der Triggerwert des Triggers 0 festgelegt. Ist Code 129, legt man die Hysterese und die Triggerflags des Triggers 0 fest. LValue und HValue bilden zusammen einen 16-Bit Wert, der den Triggerwert repräsentiert. Hyst steht für die Hysterese und Flags für die Triggerflags. Der Triggerwert, die Hysterese und auch die Triggerflags werden per Voreinstellung auf 0 gesetzt.

Der Triggerwert weist dasselbe Format auf, wie der Wert des digitalen Eingangs selbst. Dieses Format sei im Folgenden dargestellt:

LByte

Bit 7 | Bit 6 | Bit 5 | Bit 4 | Bit 3 | Bit 2 | Bit 1 | Bit 0
2 3 | 2 2 | 2 1 | 2 0 | 2 -1 | 2 -2 | 2 -3 | 2 -4

HByte

Bit 15 | Bit 14 | Bit 13 | Bit 12 | Bit 11 | Bit 10 | Bit 9 | Bit 8
S | 2 10 | 2 9 | 2 8 | 2 7 | 2 6 | 2 5 | 2 4

Abb. 4.3: Allgemeines Werteformat bei digitalen Eingängen

Das „S“ bei Bit 15 steht für „Sign“. Es handelt sich bei diesem Bit also um das Vorzeichenbit. Ist dieses 0, so handelt es sich um einen positiven Wert, andernfalls um einen negativen.

Die Hysterese besitzt das gleiche Format wie das LByte des Triggerwerts. Von den Triggerflags sind nur Bit 2 und Bit 3 relevant. Alle anderen Bits werden intern verwendet und sind bei der Konfiguration auf 0 zu setzen. Ist Bit 2 gesetzt, so wird der digitale Eingang eine Statusmeldung (siehe Kapitel 3.1.9 Statusmeldungen) generieren, sobald der aktuelle Messwert den Triggerwert unterschreitet. Eine weitere Statusmeldung folgt, wenn der Messwert mindestens wieder den Triggerwert plus Hysterese erreicht, nachdem der Triggerwert vorher unterschritten worden ist. Ist Bit 3 gesetzt, so generiert der digitale Eingang eine Statusmeldung, sobald der aktuelle Messwert den Triggerwert überschreitet. Eine weitere Statusmeldung folgt dann, wenn der Messwert mindestens wieder den Triggerwert minus Hysterese erreicht, nachdem der Triggerwert vorher überschritten worden ist. Sind diese Bits

- 53 -nicht gesetzt, bleiben die entsprechenden Statusmeldungen aus.

Die Statusmeldungen haben das Format, wie es in Kapitel 3.1.9 Statusmeldungen beschrieben ist. Während HValue und Ext 0 sind, codiert LValue den Trigger und das Ereignis, das zum Auslösen der Statusmeldung führte. Die Triggernummer des Triggers, der das Ereignis auslöste, wird in den Bits 0-2 codiert. Bit 3-5 sind immer 0. Bit 6 und Bit 7 codieren das Ereignis gemäß folgender Tabelle:

Bit 7 | Bit 6 | Ereignis
0 | 0 | Der Triggerwert plus Hysterese wurde wieder erreicht, nachdem er zuvor unterschritten wurde.
0 | 1 | Der Triggerwert wurde unterschritten.
1 | 0 | Der Triggerwert minus Hysterese wurde wieder erreicht, nachdem er zuvor überschritten wurde.
1 | 1 | Der Triggerwert wurde überschritten.

Tabelle 4.8: Ereigniscodierung bei digitalen Eingängen

Soll der aktuelle Wert eines digitalen Eingangs abgefragt werden (siehe Kapitel 3.1.8 Abfragen), so ist Select auf 0 zu setzen. Dann liefert LValue und HValue zusammen den 16-Bit Wert des Eingangs gemäß oben stehenden Formats. Hat Select die Form 1010TT00 und wird für TT die Nummer eines Triggers eingesetzt, so liefert LValue und HValue zusammen den 16-Bit Wert des entsprechenden Triggers, ebenfalls gemäß oben stehenden Formats. Entspricht Select keinem dieser Muster, wird als Ergebnis 0xFFFF zurückgeliefert.

Die Triggerwerte lassen sich auch über gewöhnliche Steuerbefehle (siehe Kapitel 3.1.7 Steuerbefehle) setzen, indem Value auf 1010TT00, wobei TT für die Nummer des entsprechenden Triggers codiert, gesetzt wird. Dann bildet LParam und HParam zusammen den 16-Bit Wert, der dem Trigger zugewiesen wird.

### 4.10.1 Dallas Digitales Thermometer

Beim Digitalen Thermometer von Dallas Semiconductor der DS1820 Reihe handelt es sich um einen digitalen Sensor, der die Umgebungstemperatur misst. Beim HAP werden zwei Varianten unterstützt, die sich gemäß ihrer Auflösung unterscheiden.

Der DS18B20 hat eine Auflösung von 12 Bit. Davon repräsentiert ein Bit das

- 54 -

Vorzeichen, 7 Bits codieren den Wert links vom Komma und 4 Bits stehen für den Wert rechts vom Komma. Das bedeutet, das die Bits 11-14 des Werts des digitalen Eingangs, so wie in Kapitel 4.10 Digitale Eingänge beschrieben, nicht verwendet werden. Diese Bits nehmen den selben Wert an, wie Bit 15. Dies führt dann zu folgendem Format:

LByte

Bit 7 | Bit 6 | Bit 5 | Bit 4 | Bit 3 | Bit 2 | Bit 1 | Bit 0
2 3 | 2 2 | 2 1 | 2 0 | 2 -1 | 2 -2 | 2 -3 | 2 -4

HByte

Bit 15 | Bit 14 | Bit 13 | Bit 12 | Bit 11 | Bit 10 | Bit 9 | Bit 8
S | S | S | S | S | 2 6 | 2 5 | 2 4

Abb. 4.4: Werteformat beim digitalen Thermometer (DS18B20)

Die nachfolgende Tabelle gibt einige Temperaturwerte und deren zugehöriges Bitmuster bzw. den entsprechenden hexadezimalen Wert wieder:

Temperatur | Wert (binär) | Wert (hexadezimal)
+125 °C | 0000 0111 1101 0000 | 07D0
+85 °C | 0000 0101 0101 0000 | 0550
+25,0625 °C | 0000 0001 1001 0001 | 0191
+10,125 °C | 0000 0000 1010 0010 | 00A2
+0,5 °C | 0000 0000 0000 1000 | 0008
0 °C | 0000 0000 0000 0000 | 0000
-0,5 °C | 1111 1111 1111 1000 | FFF8
-10,125 °C | 1111 1111 0101 1110 | FF5E
-25,0625 °C | 1111 1110 0110 1111 | FE6F
-55 °C | 1111 1100 1001 0000 | FC90

Tabelle 4.9: Temperaturcodierung beim digitalen Thermometer (DS18B20)

Der DS18S20 hat eine Auflösung von 9 Bit. Davon repräsentiert ein Bit das Vorzeichen, 7 Bits codieren den Wert links vom Komma und 1 Bit steht für den Wert rechts vom Komma. Das bedeutet, das die Bits 11-14 des Werts des digitalen Eingangs, so wie in Kapitel 4.10 Digitale Eingänge beschrieben, nicht verwendet werden. Diese Bits nehmen den selben Wert an, wie Bit 15. Die Bits 0-2 sind immer

- 55 -

0. Dies führt dann zu folgendem Format:

LByte

Bit 7 | Bit 6 | Bit 5 | Bit 4 | Bit 3 | Bit 2 | Bit 1 | Bit 0
2 3 | 2 2 | 2 1 | 2 0 | 2 -1 | 0 | 0 | 0

HByte

Bit 15 | Bit 14 | Bit 13 | Bit 12 | Bit 11 | Bit 10 | Bit 9 | Bit 8
S | S | S | S | S | 2 6 | 2 5 | 2 4

Abb. 4.5: Werteformat beim digitalen Thermometer (DS18S20)

Die nachfolgende Tabelle gibt einige Temperaturwerte und deren zugehöriges Bitmuster bzw. den entsprechenden hexadezimalen Wert wieder:

Temperatur | Wert (binär) | Wert (hexadezimal)
+85 °C | 0000 0101 0101 0000 | 0550
+25 °C | 0000 0001 1001 0000 | 0190
+0,5 °C | 0000 0000 0000 1000 | 0008
0 °C | 0000 0000 0000 0000 | 0000
-0,5 °C | 1111 1111 1111 1000 | FFF8
-25 °C | 1111 1110 0111 0000 | FE70
-55 °C | 1111 1100 1001 0000 | FC90

Tabelle 4.10: Temperaturcodierung beim digitalen Thermometer (DS18S20)

Für weitergehende Informationen über die DS1820 Reihe von Dallas sei auf die entsprechenden Datenblätter verwiesen.

### 4.11 Schalter

Geschaltete Ausgänge dienen der Ansteuerung einfacher Geräte, die lediglich die beiden Zustände aus- bzw. eingeschaltet kennen. Werden hierüber nicht nur einfache LEDs (Light Emitting Diode) gesteuert, dann im Allgemeinen Relais, die wiederum die eigentlichen Geräte schalten.

Um diese Komponente nutzen zu können, ist die entsprechende Option in der Software zu aktivieren (siehe Kapitel 3.6 Software-Management).

- 56 -

Zur Pin-Konfiguration sei auf das Kapitel 3.4 Externe Beschaltung verwiesen, wobei die Wahl des Pins keiner Restriktion unterliegt.

Ein geschalteter Ausgang kann Werte zwischen 0 und 100 annehmen – die Voreinstellung, also nach dem Einschalten einer Control Unit, ist 0, wobei jeder Wert größer 0 zum Einschalten des entsprechenden Ausgangs führt und einzig der Wert 0 den Ausgang ausschaltet.

Der Wert eines geschalteten Ausgangs kann über einen Steuerbefehl festgelegt werden (siehe Kapitel 3.1.7 Steuerbefehle). Für Value sind dabei die Werte von 0 bis 100 und der Wert 128 zulässig, der zum Invertieren des aktuellen Werts führt, das heißt, ist der aktuelle Wert größer 0, dann nimmt der Ausgang den Wert 0 an, andernfalls wird der Ausgang auf 100 gesetzt. LParam und HParam sind beide 0.

Wird der Wert eines geschalteten Ausgangs neu festgelegt – nicht unbedingt verändert, so generiert der Ausgang eine Statusmeldung (siehe Kapitel 3.1.9 Statusmeldungen). LValue ist dann der aktuelle Wert des Ausgangs, HValue und Ext sind 0.

Der aktuelle Wert eines geschalteten Ausgangs lässt sich auf herkömmliche Weise abfragen (siehe Kapitel 3.1.8 Abfragen). LValue enthält dann wieder den aktuellen Wert, HValue und Select sind 0.

### 4.12 Dimmer

Gedimmte Ausgänge sind so konzipiert, dass sie immer nur einen bestimmten einstellbaren Prozentsatz der gesamten, einer Leuchte zur Verfügung stehenden Energie, dieser auch wirklich zukommen lassen. Dies erfordert die Beschaltung des
entsprechenden | Ausgangs | mit | einer | Phasenanschnitt- | bzw. | einer
Phasenabschnittsteuerung. Die Control Unit bzw. die gedimmten Ausgänge übernehmen dann die adäquate Ansteuerung der externen Beschaltung.

Um diese Komponente nutzen zu können, ist die entsprechende Option in der Software zu aktivieren (siehe Kapitel 3.6 Software-Management).

Zur Pin-Konfiguration sei auf das Kapitel 3.4 Externe Beschaltung verwiesen, wobei die Wahl des Pins keiner Restriktion unterliegt. Es muss jedoch sichergestellt sein, dass eine Nulldurchgangserkennung der Netzspannung stattfindet und auch

- 57 -entsprechend konfiguriert ist (siehe auch hierzu Kapitel 3.4 Externe Beschaltung).

Ein gedimmter Ausgang kann Werte zwischen 0 und 100 annehmen, wobei diese Werte direkt mit dem Prozentsatz an Energie, die einem angeschlossenen Verbraucher zukommt, korrelieren. Die Voreinstellung, also nach dem Neustart der Control Unit, ist 0.

Der Wert eines gedimmten Ausgangs kann über einen Steuerbefehl festgelegt werden (siehe Kapitel 3.1.7 Steuerbefehle). Für Value sind dabei zunächst einmal die Werte zwischen 0 und 100 – siehe oben – zulässig. LParam und HParam bilden zusammen einen 16-Bit Wert, der die Zeit in Zehntelsekunden festlegt, in der die Helligkeit einer Leuchte vom aktuellen Wert auf den neuen geregelt wird. Gültige Werte sind hier 0 bis 6553.

Ist Value gleich 128 wird der aktuelle Wert des Dimmers invertiert. Das heißt, ist der aktuelle Wert größer 0, wird er auf 0 gesetzt. Andernfalls wird der Wert eingestellt, den der Dimmer hatte, bevor er ausgeschaltet wurde. Dies geschieht alles ohne Zeitverzögerung.

Ist Value gleich 129, so wird der aktuelle Wert des Dimmers um 2 % erhöht, ist er gleich 130 wird der Wert entsprechend erniedrigt. Auch hier gibt es keine Zeitverzögerung. Diese Funktion wird vor allem verwendet, wenn auf der Infrarot-Fernbedienung die Plus bzw. Minus Taste betätigt wird.

Es gibt vier weitere spezielle Steuercodes, die Verwendung finden, wenn ein Dimmer über einen Taster gesteuert wird. Ist Value gleich 133, so wird vom aktuellen Wert bis auf 100 % gedimmt, ist Value gleich 134, so wird analog auf 0 % gedimmt. Die Geschwindigkeit dieser Dimmvorgänge kann festgelegt werden, indem man die Zeit in Zehntelsekunden (Time) für einen vollständigen Dimmvorgang – also von 0 % auf 100 % bzw. umgekehrt – über folgenden Befehl konfiguriert:

VLAN Source Dest 76 36 Time 0 0

Die Voreinstellung ist 60, also 6 s. Der höchste zu vergebende Wert ist 255. Diese Einstellung gilt für alle auf der Control Unit konfigurierten Dimmer. Setzt man Value auf 135, so wird ein zuvor eingeleiteter Dimmvorgang wieder gestoppt. Mit Value gleich 136 werden die selben Vorgänge initiiert, wie bei Value gleich 133 und 134, nur immer abwechselnd. Wurde also zuletzt hochgedimmt, so wird jetzt

- 58 -herabgedimmt und umgekehrt.

Wird der Wert eines gedimmten Ausgangs neu festgelegt – nicht unbedingt verändert, so generiert der Ausgang eine Statusmeldung (siehe Kapitel 3.1.9 Statusmeldungen). Dies gilt insbesondere auch dann, wenn ein Dimmvorgang durch den Steuercode 135 (siehe voriger Abschnitt) abgebrochen wurde. LValue ist dann der aktuelle Wert des Ausgangs, HValue und Ext sind 0.

Der aktuelle Wert eines gedimmten Ausgangs lässt sich auf herkömmliche Weise abfragen (siehe Kapitel 3.1.8 Abfragen). LValue enthält dann wieder den aktuellen Wert, HValue und Select sind 0.

Ist bei der Pin-Konfiguration (siehe Kapitel 3.4 Externe Beschaltung) die Option Soft-Delay aktiviert worden, so dauert jeder Dimmvorgang mindestens 3 Zehntelsekunden, egal ob eine kürzere Zeit in dem entsprechenden Steuerbefehl hinterlegt wurde. Es kann so ein smartes Ein- bzw. Ausschalten gewährleistet werden.

Die Option Lange Zündimpulse bewirkt, dass die Triacs der externen Beschaltung nicht mit kurzen Impulsen gezündet werden, sondern die Impulslänge bis zum nächsten Nulldurchgang der Netzspannung ausgedehnt wird. Ist die Option Phasenabschnittsteuerung (siehe unten) aktiviert, darf diese Option nicht aktiviert werden. Ist diese Option nicht aktiviert kann insbesondere die Länge der Zündimpulse über den Befehl

VLAN Source Dest 76 37 LTics HTics 0

eingestellt werden. LTics und HTics bilden dabei zusammen einen 16-Bit Wert, der die Länge der Zündimpulse in Tics angibt. Eine Halbwelle besteht aus 15000 Tics. Die Voreinstellung ist 60. Diese Einstellung gilt für alle auf der Control Unit konfigurierten Dimmer.

Eine weitere Option ist die Schaltrestriktion. Ein gedimmter Ausgang verhält sich bei deren Aktivierung genau wie ein geschalteter Ausgang. Ist der Wert des Ausgangs größer 0, so wird der Ausgang eingeschaltet, also auf 100 % gesetzt. So lässt sich der sichere Betrieb von Geräten gewährleisten, die nicht gedimmt werden können, aber dennoch über eine Dimmerstufe angesteuert werden können, wie z. B. Fernseher.

- 59 -

Die Option Phasenabschnittsteuerung muss aktiviert werden, wenn es sich bei der externen Beschaltung um eben eine solche handelt. Andernfalls wird von einer Beschaltung mit einer Phasenanschnittsteuerung ausgegangen.

### 4.13 Abstraktes Modul

In den vorigen Kapiteln wurden Software Komponenten beschrieben, die zur Ansteuerung einfacher Geräte, wie Leuchten oder Fernseher, bzw. zur Erfassung
von Messwerten | über einfache | Sensoren, | wie | Helligkeitssensor oder
Temperaturfühler, über entsprechende externe Beschaltungen genutzt werden können. Daneben gibt es Komponenten, die zur Steuerung komplexer Geräte, wie Rollläden oder Drehgeber genutzt werden. Diese unterscheiden sich von den Komponenten zur Steuerung einfacher Geräte dadurch, dass sie diese Geräte nicht direkt steuern, sondern sich eben dieser einfachen Komponenten bzw. Geräten bedienen.

Diese Geräte werden also nicht mit einem konkreten Pin verbunden, sondern existieren als rein logische bzw. abstrakte Objekte innerhalb einer Control Unit. Zur Verwaltung und zum Management dieser Objekte, sowie zu deren Konfiguration wird diese Komponente benötigt.

Es können bis zu 4 abstrakte Objekte konfiguriert werden. Mit folgendem Befehl wird ein neues abstraktes Objekt angelegt:

VLAN Source Dest 96 0 Addr Type SModul

Addr ist die Geräte-Adresse des abstrakten Objekts, Type der Typ (Code + Offset) des Objekts gemäß unten stehender Tabelle und SModul die Moduladresse, an die das Objekt seine Statusmeldungen verschickt. Ist diese 0, wird das Versenden jeglicher Statusmeldungen unterbunden. Entspricht die Adresse der Moduladresse des Moduls, auf dem das Objekt konfiguriert ist, wird die Statusmeldung nur lokal verarbeitet und nicht versendet. Soll eine Statusmeldung lediglich von der Central Control Unit verarbeitet werden, so wird deren Adresse hier eingesetzt. Analoges gilt für jede andere Control Unit. Broadcasts und Multicasts können hier in gewohnter Weise verwendet werden.

- 60 -

Code | Offset | Objekt-Typ
192 | 0 | Rollladensteuerung
224 | 0 | Drehgeber
240 | 0 | GUI (Graphical User Interface)

Tabelle 4.11: Typen abstrakter Objekte

Die Konfiguration aller anderen Eigenschaften, die ein abstraktes Objekt haben kann, wird in den entsprechenden Kapiteln beschrieben.

### 4.14 Rollladensteuerung

Diese Komponente dient der Ansteuerung eines Rollladens, einer Leinwand oder eines in ihrer Steuerfunktion vergleichbaren Geräts.

Um diese Komponente nutzen zu können, ist die entsprechende Option in der Software zu aktivieren (siehe Kapitel 3.6 Software-Management).

Die Grundkonfiguration ist gemäß Kapitel 4.13 Abstraktes Modul vorzunehmen. Eine Rollladensteuerung basiert auf zwei elementaren Steuerungen zum Betrieb des entsprechenden Motors in Auf- und Abwärtsrichtung. Hier können sowohl geschaltete als auch gedimmte Ausgänge eingesetzt werden, sofern die Parametrierung auf das zu steuernde Gerät passt (siehe Kapitel 4.11 Schalter und 4.12 Dimmer). Die Rollladensteuerung schaltet den entsprechenden Ausgang solange ein, bis der eingestellte Wert für den Rollladen erreicht ist. Mit dem Befehl

VLAN Source Dest 96 RSAddr 0 Modul Addr

wird der Ausgang konfiguriert, der den Rollladenmotor zur Aufwärtsfahrt aktiviert. RSAddr ist dabei die Geräte-Adresse des Rollladens, so wie sie beim Anlegen des Rollladenobjekts vergeben wurde. Modul ist die Modul-Adresse des Ausgangs und Addr die Geräte-Adresse desselben. Analog wird der Ausgang zur Abwärtsfahrt des Rollladens wie folgt konfiguriert:

VLAN Source Dest 96 RSAddr 1 Modul Addr

Damit die Rollladensteuerung errechnen kann, wie lange der Motor in die entsprechende Richtung angesteuert werden muss, um die vorgegebene Position zu

- 61 -erreichen, ist die maximale Fahrzeit des Rollladens (von 100 % auf 0 % - also eine Aufwärtsfahrt, die Abwärtsfahrt dauert gegebenenfalls, bedingt durch das Gewicht des Rollladens, nicht ganz so lange) zu konfigurieren. Dies geschieht mit dem Befehl

VLAN Source Dest 96 RSAddr 128 Time 0

Time gibt dabei die maximale Fahrzeit in Fünftelsekunden an. Mit dem Befehl

VLAN Source Dest 96 RSAddr 129 Type 0

wird der Typ des Rollladens festgelegt. Von Type wird nur Bit 0 verwendet. Ist es nicht gesetzt, verhält sich die Steuerung wie oben beschrieben. Andernfalls werden die Ausgänge über Impulse der Länge 3/5 s gesteuert. Das heißt, die Steuerlogik des Rollladenmotors bekommt einen Impuls zum Anfahren und einen weiteren, wenn der Motor wieder gestoppt werden soll.

Ein Rollladen kann Werte zwischen 0 und 100 annehmen, wobei diese Werte dem Prozentsatz der Geschlossenheit entsprechen, das heißt, 100 % steht für einen geschlossenen und 0 % für einen vollständig eingefahrenen Rollladen. Die Voreinstellung, also nach dem Neustart der Control Unit, ist 0.

Der Wert eines Rollladens kann über einen Steuerbefehl festgelegt werden (siehe Kapitel 3.1.7 Steuerbefehle). Für Value sind dabei zunächst einmal die Werte zwischen 0 und 100 – siehe oben – zulässig. LParam und HParam sind 0.

Ist Value gleich 128 wird der aktuelle Wert des Rollladens invertiert. Das heißt, ist der aktuelle Wert größer 0, wird er auf 0 gesetzt, der Rollladen also vollständig eingefahren. Andernfalls wird der Wert auf 100 gesetzt, der Rollladen also vollständig geschlossen. Erreicht der Steuerbefehl den Rollladen, während dieser gerade in Bewegung ist, so wird er gestoppt.

Es gibt vier weitere spezielle Steuercodes, die Verwendung finden, wenn ein Rollladen über einen Taster gesteuert wird. Ist Value gleich 133, so wird er vom aktuellen Wert bis auf 100 % gefahren, ist Value gleich 134, so wird analog auf 0 % gefahren. In beiden Fällen gilt, dass wenn der Rollladen beim Empfang des Steuerbefehls in Bewegung war, die Fahrt gestoppt wird. Setzt man Value auf 135, so wird eine zuvor eingeleitete Fahrt wieder gestoppt. Mit Value gleich 136 werden die selben Vorgänge initiiert, wie bei Value gleich 133 und 134, nur immer

- 62 -abwechselnd. Wurde also zuletzt hochgefahren, so wird jetzt heruntergefahren und umgekehrt.

Wird der Wert eines Rollladens neu festgelegt – nicht unbedingt verändert, so generiert der Ausgang eine Statusmeldung (siehe Kapitel 3.1.9 Statusmeldungen). Dies gilt insbesondere auch dann, wenn eine Fahrt durch den Steuercode 135 (siehe voriger Abschnitt) abgebrochen wurde. LValue ist dann der aktuelle Wert des Rollladens, HValue und Ext sind 0.

Der aktuelle Wert eines Rollladens lässt sich auf herkömmliche Weise abfragen (siehe Kapitel 3.1.8 Abfragen). LValue enthält dann wieder den aktuellen Wert, HValue und Select sind 0.

Wird versucht, den Wert eines Rollladens neu festzulegen, während dieser sich in Bewegung befindet – oben beschriebene spezielle Steuercodes sind davon ausgenommen, wird eine „Device Busy“ Fehlermeldung generiert (siehe Kapitel 3.1.11 Fehlerbehandlung).

### 4.15 Drehgeber

Diese Komponente unterstützt den Betrieb von Drehgebern, wie sie im Allgemeinen als Eingabegerät im Zusammenhang mit GUIs (Graphical User Interfaces) eingesetzt werden. Sie liefern unterschiedliche Signale, wenn man in verschiedene Richtungen dreht oder den Taster betätigt. Diese Software-Komponente wandelt diese Signale in solche um, wie sie zur Weiterverarbeitung durch andere Geräte oder Bedienoberflächen benötigt werden.

Um diese Komponente nutzen zu können, ist die entsprechende Option in der Software zu aktivieren (siehe Kapitel 3.6 Software-Management). Insbesondere ist dabei auf den richtigen Typ von Drehgeber zu achten.

Die Grundkonfiguration ist gemäß Kapitel 4.13 Abstraktes Modul vorzunehmen. Ein Drehgeber hat 3 Anschlüsse, zwei für die Signale zur Erfassung der Drehung und einen für die Tastfunktion, hier willkürlich mit A, B und T bezeichnet. Zur Erfassung dieser Signale wird für jeden Anschluss ein logischer Eingang konfiguriert (siehe Kapitel 4.8 Logische Eingänge). Dem Drehgeber müssen diese Eingänge dann zugeordnet werden. Hierzu wird zunächst die Modul-Adresse der Control Unit

- 63 -konfiguriert, an der der Drehgeber angeschlossen ist.

VLAN Source Dest 96 DGAddr 0 Modul 0

DGAddr ist die Geräte-Adresse des Drehgebers, so wie sie bei der Grundkonfiguration vergeben wurde und Modul die zu konfigurierende Modul-Adresse. Es folgen der Reihe nach die Geräte-Adressen der logischen Eingänge A, B und T.

VLAN Source Dest 96 DGAddr 1 AddrA 0

VLAN Source Dest 96 DGAddr 2 AddrB 0

VLAN Source Dest 96 DGAddr 3 AddrT 0

AddrX ist dabei die jeweils zu konfigurierende Geräte-Adresse. Schließlich muss noch das Gerät spezifiziert werden, das durch den Drehgeber angesteuert werden soll, also im Allgemeinen eine Bedienoberfläche. Hierzu wird der Befehl

VLAN Source Dest 96 DGAddr 4 Modul Addr

verwendet, wobei Modul die Modul-Adresse und Addr die Geräte-Adresse des anzusteuernden Geräts ist.

Die logischen Eingänge der Anschlüsse A und B sind für Steigende Flanke, Fallende Flanke und Prellfreiheit zu konfigurieren. Der logische Eingang des Anschluss T ist so zu konfigurieren, dass sich das gewünschte Verhalten ergibt, es muss jedoch mindestens die Prellfreiheit konfiguriert werden. Ferner ist darauf zu achten, dass die Statusmeldungen, die von den logischen Eingängen verschickt werden, den Drehgeber auch erreichen, die entsprechende Modul-Adresse für diese Meldungen also korrekt konfiguriert wurde.

Detektiert der Drehgeber ein Ereignis – eine Drehung oder einen Tastendruck, so gibt er dieses Ereignis als Steuerbefehl (siehe Kapitel 3.1.7 Steuerbefehle) an das konfigurierte Ausgabegerät weiter. Ist das Ereignis eine Drehung, wird als Value die Drehrichtung angegeben (Links = 137, Rechts = 138), in LParam wird die Geschwindigkeit der Drehung hinterlegt (siehe unten) und HParam ist 0. Handelt es sich bei dem Ereignis um einen Tastendruck, steht in Value die Länge des Tastendrucks (Kurz = 139, Medium = 140, Lang = 141) und LParam und HParam

- 64 -

sind 0.

Die Drehgeschwindigkeit des Drehgebers kann individuell angepasst werden. Mit dem Befehl

VLAN Source Dest 96 DGAddr 5 Speed 0

lässt sie sich festlegen, wobei Speed eben den Wert der Drehgeschwindigkeit spezifiziert. Bei der Detektion eines Drehereignisses setzt der Drehgeber einen internen Zähler auf diesen konfigurierten Wert. Dann wird dieser alle Hundertstelsekunde decrementiert, bis ein weiteres Drehereignis detektiert wird oder der Zähler 0 geworden ist. Dieser Zählerstand wird dann, wie oben beschrieben, in LParam hinterlegt. Die Interpretation dieses Werts obliegt dann dem Zielgerät. Insofern sei hier auf die entsprechenden Kapitel verwiesen.
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

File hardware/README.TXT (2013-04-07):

Parts list:

HAP-ControlUnit-3.0: 
http://www.reichelt.de/?ACTION=20;AWKID=64257;PROVID=2084

Required Voltage-Regulator:
http://www.csd-electronics.de Part-Nr.: 2229 (LF50CDT)

HAP-ControlUnit-DIL-3.0:
http://www.reichelt.de/?;ACTION=20;LA=5010;AWKID=139808;PROVID=2084

Required MCP2515 DIL-Version:
http://www.csd-electronics.de Part-Nr.: 30486 (MCP2515-I/P)

HAP-USB-3.0: 
http://www.reichelt.de/?ACTION=20;AWKID=17196;PROVID=2084

HAP-LCD-1.0: 
http://www.reichelt.de/?ACTION=20;AWKID=8974;PROVID=2084

HAP-ZCD-3.0: 
http://www.reichelt.de/?ACTION=20;AWKID=8070;PROVID=2084

HAP-CU-Hutschiene-3.0: 
http://www.reichelt.de/?ACTION=20;AWKID=8056;PROVID=2084

HAP-5xMosFet-1.0: 
http://www.reichelt.de/?ACTION=20;AWKID=8055;PROVID=2084

HAP-5xDimmer-3.1: 
http://www.reichelt.de/?ACTION=20;AWKID=96183;PROVID=2084

HAP-6xRelais-3.1: 
https://secure.reichelt.de/index.html?;ACTION=20;AWKID=730469;PROVID=2084

HAP-4xJalousieaktor-1.0:
http://www.reichelt.de/?ACTION=20;AWKID=174350;PROVID=2084

HAP-4xPolwender-1.0:
http://www.reichelt.de/?ACTION=20;AWKID=174350;PROVID=2084

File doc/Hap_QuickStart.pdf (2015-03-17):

HAP Quickstart-Guide V 0.1 | 2010-03-21

Zunächst möchte ich mich erstmal wirklich bei den Erschaffern von HAP bedanken. Im Netz findet man selten ein Projekt was so durchdacht ausgearbeitet wurde und ich hoffe mit der Quickstart-Anleitung auch Einsteigern die ersten Schritte etwas zu vereinfachen. Man findet alle Infos auch in der vollständigen Dokumentation aber es ist weit verstreut und daher wollte ich das gröbste einmal zusammenfassen. Der Ablauf funktioniert so wunderbar und bei Detailfragen ist ein Blick in die „Technische Dokumentation“ im Wiki sehr hilfreich.

Diese Zusammenfassung basiert auf Informationen von http://home-automation-project.netmb.net/ (http://home-automation-project.netmb.net/) und dem Mikrocontroller-Forum.

Über Ergänzungen oder Verbesserungen würde ich mich freuen!

Vorraussetzungen zur Nutzung:

- Windows PC mit AVR-Studio & WinAVR
- Ubuntu 9.04
- 1-2 aufgebaute Controller-Units (CU)
- Hterm (Terminalsoftware) für Linux/Windows
- USB oder RS232 Interface

### 1. Installation von Ubuntu 9.04

- Installation von Ubuntu Version 9.04
- In der Konsole mit sudo:

wget http://packages.netmb.net/PublicKey
apt-key add PublicKey
echo "deb http://packages.netmb.net/ubuntu ./" >> /etc/apt/sources.list
apt-get update
apt-get install hap

Nach der erfolgreichen Installation der HAPConfig sollte man vor dem Start noch definieren, wie die Kommunikation zwischen HAP-Server und den CU's erfolgen soll. Dazu muss die folgende Datei editiert werden:

cd /opt/hap/etc/
sudo gedit hap.yml

Sofern noch keine CU's vorhanden sind einfach die eigene Rechner IP verwenden, damit der Server ohne Fehler starten kann.

ServerCUConnection:
Type: 'Network'
Host: 192.xxx.xxx.xxx
Port: 4567
#ServerCUConnection:

# Type: 'Serial'

# Ports: [ '/dev/ttyUSB1' ]

Sofern CU's schon vorhanden sind kann man die Schnittstelle eintragen

#ServerCUConnection:

# Type: 'Network'

# Host: 192.xxx.xxx.xxx

# Port: 4567

ServerCUConnection:
Type: 'Serial'
Ports: [ '/dev/ttyUSB1' ] # hier die benutzte Schnittstelle eintragen!

Danach sollte der Start möglich sein (HAP neustarten vorher):

HAPConfig : http://192.xxx.xxx.xxx :8090
HAP-GUI : http://192.xxx.xxx.xxx :8090/GUI

### 2. Erstellung der Firmware (CU)

Vorab sollte man im HAPConfig über Tools->DownloadBootlader den Bootloader exportieren, um diesen auf die CU zu flashen. Die muss für jede CU einzeln gemacht werd. Dadurch wird automatisch eine UID im Bootloader eingesetzt und macht später die CU indentifizierbar.

Die UID (6 Zeichen) selber steht im Bootloader bzw. im Namen:

HAPBootLoader-0F2C07.hex

Das direkte Importieren des Projekts klappte bei mir leider nicht, daher:
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

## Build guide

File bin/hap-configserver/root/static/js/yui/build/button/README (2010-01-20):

*** Version 2.5.1 ***

+ No changes.

*** Version 2.5.0 ***

+ Fixed issue where returning false inside the scope of a listener for attribute "before" 
  events (i.e "beforeCheckedChange") would not cancel the attribute's default setter.

*** Version 2.4.1 ***

+ No changes.

*** Version 2.4.0 ***

Added the following features:
-----------------------------

+ Added a static method "YAHOO.widget.Button.getButton" that returns a Button 
  instance with the specified HTML element id.

Fixed the following bugs:
-------------------------

+ Removed the ".yui-skin-sam" CSS class name from style rules in the core 
  stylesheet so that it is now truly skin agnostic.

+ Updated the default text for tooltips for Buttons of type "radio" so that 
  they offer the correct instructional text.

+ Menus with grouped YAHOO.widget.MenuItem instances will now highlight 
  correctly when used with Button.

+ Buttons of type "link" now have the same default height as other Button
  types in Internet Explorer.

+ Buttons of various types now line up correctly on the same line.

+ Menu is now truly an optional dependancy of Button.

+ Menus now render with the correct width when the "yui-skin-sam" CSS class 
  name is applied to an element other than the <BODY>.

*** Version 2.3.1 ***

Fixed the following bugs:
-------------------------
+ Purged the old 2.2.2 Button stylesheet and related image assets that was 
  mistakenly included in the 2.3.0 build.

+ Fixed an issue in Gecko where changing a Button instance's "label" attribute
  after the Button had been created would not result in the Button redrawing at
  a width to fit its content.
  
+ Fixed an issue where the singleton keypress event handler
  (YAHOO.widget.Button.onFormKeyPress) registered for forms containing
  Button instances of type "submit" was not removed from the form once all of 
  its child Button instances are destroyed.

+ Submitting a form by clicking on a MenuItem of a SplitButton's or MenuButton's
  Menu will no longer result in a JavaScript error.
  
+ Modified how element tag names are compared to support XHTML applications.

+ Added code to remove the CSS class names representing the "hover," "focus," 
  and "active" states when a Button instance is disabled.

*** Version 2.3 ***

Added the following features:
-----------------------------

+ Added a "focusmenu" configuration attribute that controls whether or not a 
  Button instance's menu will automatically be focused when made visible. 

+ Added a "lazyloadmenu" configuration attribute that controls the value of 
  the "lazyload" configuration property of a Button's menu.

+ Added "menuclassname" configuration attribute that defines a CSS class name
  to be applied to the root HTML element of a button's menu.

Fixed the following bugs:
-------------------------

+ Setting the "label" attribute of a Button of type "link" to a string with 
  a "www." prefix will no longer result in the value of the "href" property 
  being used for the "label" in IE.

+ Disabling a Button when its menu is visible will now result in the menu 
  being hidden.

+ Hidden field(s) created by a Button instance are now removed if the 
  submission of its parent form is cancelled.

+ If a Button instance is preceeded by another enabled HTML submit button 
  (<input type="submit" ...> or <button type="submit" ...>), it will no longer 
  create a hidden field representing its name and value when its parent form 
  is submitted.

+ If an HTML form contains a mix of YUI Buttons of type "submit" and standard 
  HTML submit buttons (<input type="submit" ...> or <button type="submit" ...>) 
  its "submit" event will no longer fire twice when it is submitted by the user 
  pressing the enter key while focus inside another HTML form control.

+ If all Button instances in a form are disabled, the form will no longer be 
  submitted when the user presses the enter key while focused inside another 
  HTML form control.

+ The first enabled Button instance in a form now correctly adds its name and 
  value to the form's data set when the form is submitted by the user pressing 
  the enter key while focused inside another form control.  

+ Fixed typo in the source file for the ButtonGroup class that was causing the 
  private variable "m_oButtons" to be declared as a global.

+ Switched to use of the CSS display type "-moz-inline-box" from 
  "-moz-inline-stack" for Gecko-based browsers so that the entire area of a 
  Button instance is clickable when it is rendered inside another inline 
  element.

+ Added "yui-button" and "yui-[button type]-button" prefix to CSS classes to 
  sandbox Button styles.

Changes:
--------

+ Default value of "type" configuration attribute now "push" (was "button").

+ Type "menubutton" now "menu."

+ Type "splitbuton" now "split."

+ Added "addStateCSSClasses" method.

+ Added "removeStateCSSClasses" method.

+ Renamed protected property "_hiddenField" to "_hiddenFields."

+ Removed protected "submit" event handler named "_onFormSubmit."

+ Renamed public method "createHiddenField" to "createHiddenFields."

+ Added new "removeHiddenFields" method.

+ Renamed static method "YAHOO.widget.Button.onFormKeyDown" 
  to "YAHOO.widget.Button.onFormKeyPress."

+ Renamed "TAG_NAME" constant (YAHOO.widget.Button.prototype.TAG_NAME and 
  YAHOO.widget.ButtonGroup.prototype.TAG_NAME) to 
  "NODE_NAME" (YAHOO.widget.Button.prototype.NODE_NAME and 
  YAHOO.widget.ButtonGroup.prototype.NODE_NAME).

+ The "selectedMenuItem" configuration attribute now correctly gets/sets the 
  index of the selected MenuItem instance of the button's menu, rather than a
  MenuItem instance.

+ The "container" configuration attribute is now writeonce

+ The "menu" configuration attribute is now writeonce

+ The root element of each button's menu now will have two CSS classes 
  appended to it:
    - The CSS class name specified by the "menuclassname" configuration 
      attribute (by default is "yui-button-menu")
    - A type-specific class name (either "yui-split-button-menu" 
      or "yui-menu-button-menu")

+ "menu" configuration attribute now supports creation or use of 
  YAHOO.widget.Overlay in addition to previously supported 
  YAHOO.widget.Menu:
  
	- To create a menu from existing markup using YAHOO.widget.Overlay, pass the
	  id or node reference of the HTML element to be used to create the Overlay 
	  as the value of the "menu" configuration attribute.

    - YAHOO.widget.Overlay instances passed as a value for the "menu" 
      configuration attribute need to be fully rendered.  

	- To create a menu from existing markup using YAHOO.widget.Menu, pass the 
	  id or node reference of the HTML element to be used to create the menu 
	  as the value of the "menu" configuration attribute and give the 
	  HTML element the same class name as specified by 
	  YAHOO.widget.Menu.prototype.CSS_CLASS_NAME.
	
	- YAHOO.widget.Overlay instances used as a menu are by default not rendered 
	  until they are are made visible for the first time.  This behavior 
	  can be changed so that they are rendered immediately by setting the value 
	  of the "lazyloadmenu" configuration attribute to "false."

+ If you pass an element id for the value of the "menu" configuration 
  attribute, that node is now accessed immediately via the "get" method of the 
  Dom utility (YAHOO.util.Dom) as opposed to the "onContentReady" method of the
  Event utility (YAHOO.util.Event).

+ Modified code to support a more generic markup format.  Now any number of 
  HTML elements can exist between a Button's root HTML element and its button 
  node (be it an <A> or <BUTTON> element):

    <ROOT_NODE> ... <BUTTON_NODE /> ... </ROOT_NODE>

+ A Button can now be initialized using any of the following six HTML patterns:

    - <A> TEXT/HTML </A>
    - <BUTTON> TEXT/HTML </BUTTON>
    - <INPUT />
    - <ROOT_NODE> ... <A> TEXT/HTML </A> ... </ROOT_NODE>
    - <ROOT_NODE> ... <BUTTON> TEXT/HTML </BUTTON> ... </ROOT_NODE>
    - <ROOT_NODE> ... <INPUT /> ... </ROOT_NODE>

+ The id of a Button instance can now match that of its source element.

+ CSS changes:

    1) All Buttons have a "yui-" prefix as opposed to "yui":
    
    2.2.2	    | 2.3
    -------------------------
    .yuibutton  | .yui-button

    2) Each Button type has its own class name with a "yui-" prefix and 
    "-button" suffix IN ADDITION TO the default "yui-button" class name:
    
    2.2.2			| 2.3
    ------------------------------------------
    .yuibutton.splitbutton	| .yui-split-button
    .yuibutton.menubutton	| .yui-menu-button
    
    * Allows for the definition of generic styles that apply to all buttons, 
    while providing a means for uniquely styling buttons of a specific type.

    3) For states that are common to all Buttons, two classes are applied: a
    generic class name (i.e. yui-button-[state]) and a type-specific state class
    name (yui-[type]-button-[state]):
    
    2.2.2			| 2.3
    -------------------------------------------
    .yuibutton.focus	| .yui-button-focus
    .yuibutton.radio.focus	| .yui-radio-button-focus
    
    * States common to all Button types are:
        + focus
        + hover
        + active
        + disabled
    
    ** Allows for the definition of generic styles that apply to all states of 
    all buttons, while providing a means for uniquely styling states for 
    buttons of a specific type.

    4) Buttons of type "radio" and "checkbox" have two classes applied to 
    represent their "checked" state: a generic class name 
    (i.e. yui-button-checked) and a type-specific class 
    name (yui-[type]-button-checked):
    
    2.2.2			    | 2.3
    -------------------------------------------
    .yuibutton.checked	    | .yui-button-checked
    .yuibutton.radio.checked    | .yui-radio-button-checked
    .yuibutton.checkbox.checked | .yui-checkbox-button-checked
    
    ** This allows for the definition of a universal style for all Buttons that
    have a "checked" state or the ability to define a type-specific style for 
    the "checked" state.

    5) States that are specific to a particular type only get a type-specific 
    state class name.  Currently this only applies to the "splitbutton" type:
    
    2.2.2			    | 2.3
    -------------------------------------------
    .yuibutton.activeoption     | .yui-split-button-activeoption

    6) The "ie6" class name is removed.

*** Version 2.2.2 ***

+ No changes

*** Version 2.2.1 ***

Added the following features:
-----------------------------

+ Added "getHiddenField" method to YAHOO.widget.Button.

Fixed the following bugs:
-------------------------

+ Removed built-in use of the Event utility's "onAvailable" method from the
  constructor of Button and ButtonGroup as it was preventing the addition of 
  event listeners on instances created from existing markup.  Going forward 
  Button and ButtonGroup instances created from existing markup can only be 
  instantiated once their source HTML element is available in the DOM.  The 
  Button examples illustrate how this can be accomplished.

+ Modified code so that disabled Button instances no longer fire DOM events.

+ Pressing the enter key while focused on a form field whose parent form 
  contains a Button instance of type "submit" will now automatically submit 
  the form using the first Button instance of type "submit".

+ Clicking a Button instance of type="submit" will now cause the Button's 
  parent form's "submit" event to fire.

+ Modified Button CSS so that the filter used to apply alpha transparency to 
  a Button's background PNG is only used by IE 6.  The previous code was 
  enabling IE's Alpha image loader for IE 7 in Quirks mode. 

+ Fixed documentation error for "getForm" method.  

Changes:
--------

+ Made the "submitForm" method of YAHOO.widget.Button public (was 
  previously protected).  

+ Removed "init" event and corresponding "oninit" configuration attribute
  from YAHOO.widget.Button and YAHOO.widget.ButtonGroup.

+ Added the CSS class "ie6" to button.css.  This classname is append to root 
  DOM element of Button instances created with IE 6.  By default this class
  is used to apply a filter that gives alpha transparency to a Button's 
  background PNG.

*** Version 2.2.0 ***

* Button Control introduced

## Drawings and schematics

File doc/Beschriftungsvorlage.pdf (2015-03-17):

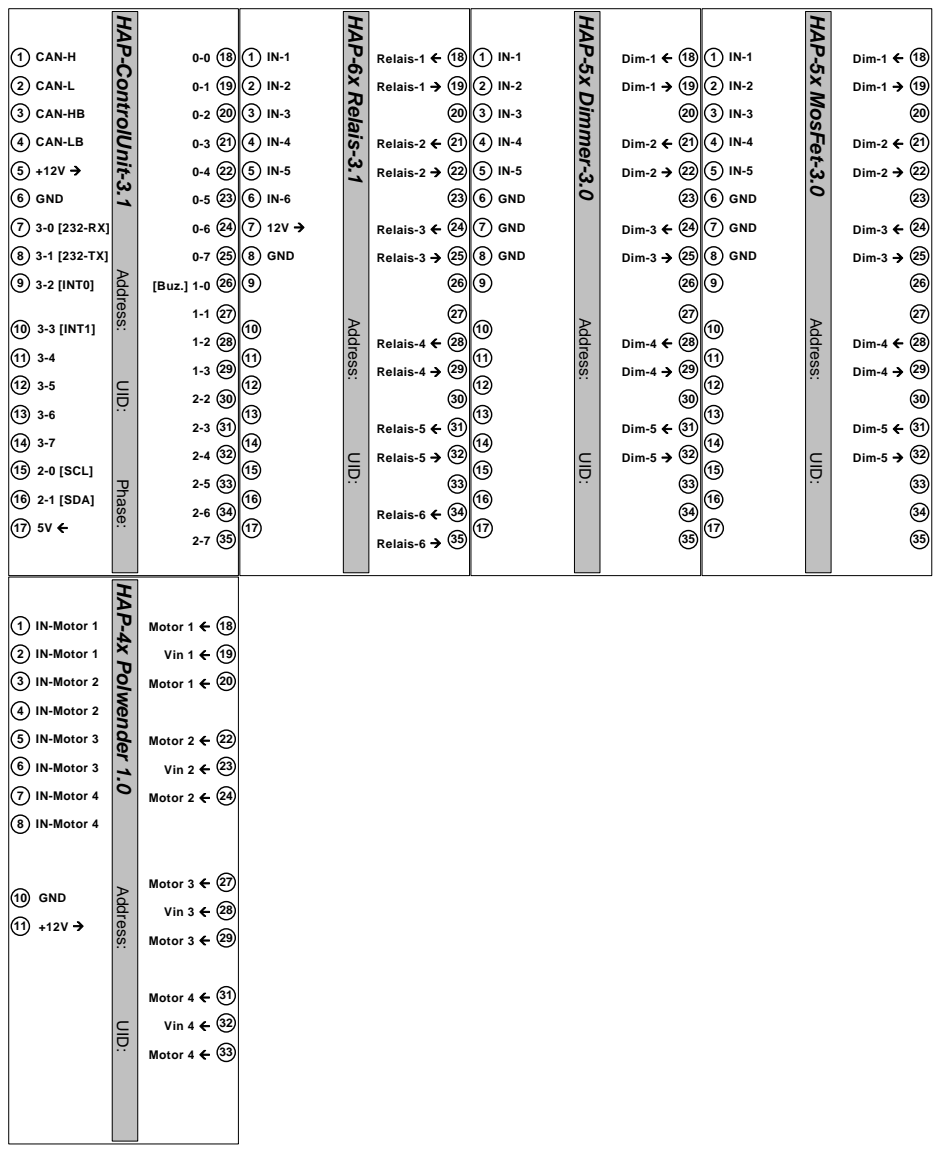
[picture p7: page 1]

HAP-ControlUnit-3.1 Address: UID: Phase:

HAP-6x Relais-3.1 Address: UID:

HAP-5x Dimmer-3.0 Address: UID:

HAP-5x MosFet-3.0 Address: UID:

HAP-4x Polwender 1.0 Address: UID:

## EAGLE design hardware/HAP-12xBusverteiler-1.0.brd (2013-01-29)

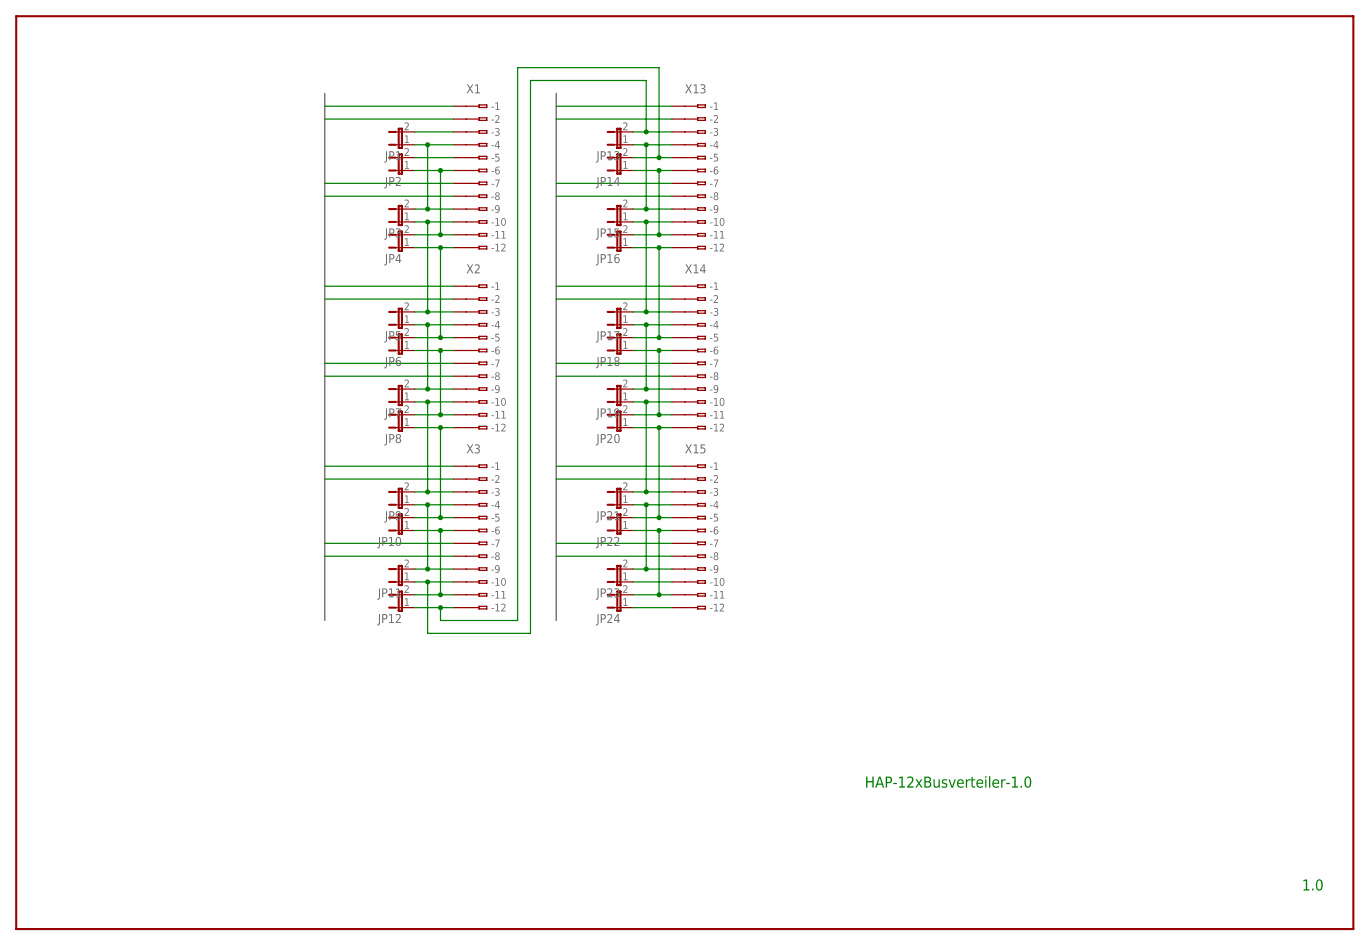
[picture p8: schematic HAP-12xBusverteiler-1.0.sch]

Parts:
JP1, JP2, JP3, JP4, JP5, JP6, JP7, JP8, JP9, JP10, JP11, JP12, JP13, JP14, JP15, JP16, JP17, JP18, JP19, JP20, JP21, JP22, JP23, JP24: JP1E; JP1
X1, X2, X3, X13, X14, X15: 233-512

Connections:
12V: X1.B1 (B-1), X1.B7 (B-7), X2.B1 (B-1), X2.B7 (B-7), X3.B1 (B-1), X3.B7 (B-7), X13.B1 (B-1), X13.B7 (B-7), X14.B1 (B-1), X14.B7 (B-7), X15.B1 (B-1), X15.B7 (B-7)
GND: X1.B2 (B-2), X1.B8 (B-8), X2.B2 (B-2), X2.B8 (B-8), X3.B2 (B-2), X3.B8 (B-8), X13.B2 (B-2), X13.B8 (B-8), X14.B2 (B-2), X14.B8 (B-8), X15.B2 (B-2), X15.B8 (B-8)
unnamed: JP1.1, JP3.2, X1.B4 (B-4), X1.B9 (B-9)
unnamed: JP3.1, JP5.2, X1.B10 (B-10), X2.B3 (B-3)
unnamed: JP5.1, JP7.2, X2.B4 (B-4), X2.B9 (B-9)
unnamed: JP13.1, JP15.2, X13.B4 (B-4), X13.B9 (B-9)
unnamed: JP14.1, JP16.2, X13.B6 (B-6), X13.B11 (B-11)
unnamed: JP15.1, JP17.2, X13.B10 (B-10), X14.B3 (B-3)
unnamed: JP16.1, JP18.2, X13.B12 (B-12), X14.B5 (B-5)
unnamed: JP2.1, JP4.2, X1.B6 (B-6), X1.B11 (B-11)
unnamed: JP4.1, JP6.2, X1.B12 (B-12), X2.B5 (B-5)
unnamed: JP6.1, JP8.2, X2.B6 (B-6), X2.B11 (B-11)
unnamed: JP7.1, JP9.2, X2.B10 (B-10), X3.B3 (B-3)
unnamed: JP17.1, JP19.2, X14.B4 (B-4), X14.B9 (B-9)
unnamed: JP18.1, JP20.2, X14.B6 (B-6), X14.B11 (B-11)
unnamed: JP19.1, JP21.2, X14.B10 (B-10), X15.B3 (B-3)
unnamed: JP1.2, X1.B3 (B-3)
unnamed: JP2.2, X1.B5 (B-5)
unnamed: JP20.1, JP22.2, X14.B12 (B-12), X15.B5 (B-5)
unnamed: JP21.1, JP23.2, X15.B4 (B-4), X15.B9 (B-9)
unnamed: JP8.1, JP10.2, X2.B12 (B-12), X3.B5 (B-5)
unnamed: JP9.1, JP11.2, X3.B4 (B-4), X3.B9 (B-9)
unnamed: JP22.1, JP24.2, X15.B6 (B-6), X15.B11 (B-11)
unnamed: JP10.1, JP12.2, X3.B6 (B-6), X3.B11 (B-11)
unnamed: JP11.1, JP13.2, X3.B10 (B-10), X13.B3 (B-3)
unnamed: JP23.1, X15.B10 (B-10)
unnamed: JP12.1, JP14.2, X3.B12 (B-12), X13.B5 (B-5)
unnamed: JP24.1, X15.B12 (B-12)

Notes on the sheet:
HAP-12xBusverteiler-1.0
1.0

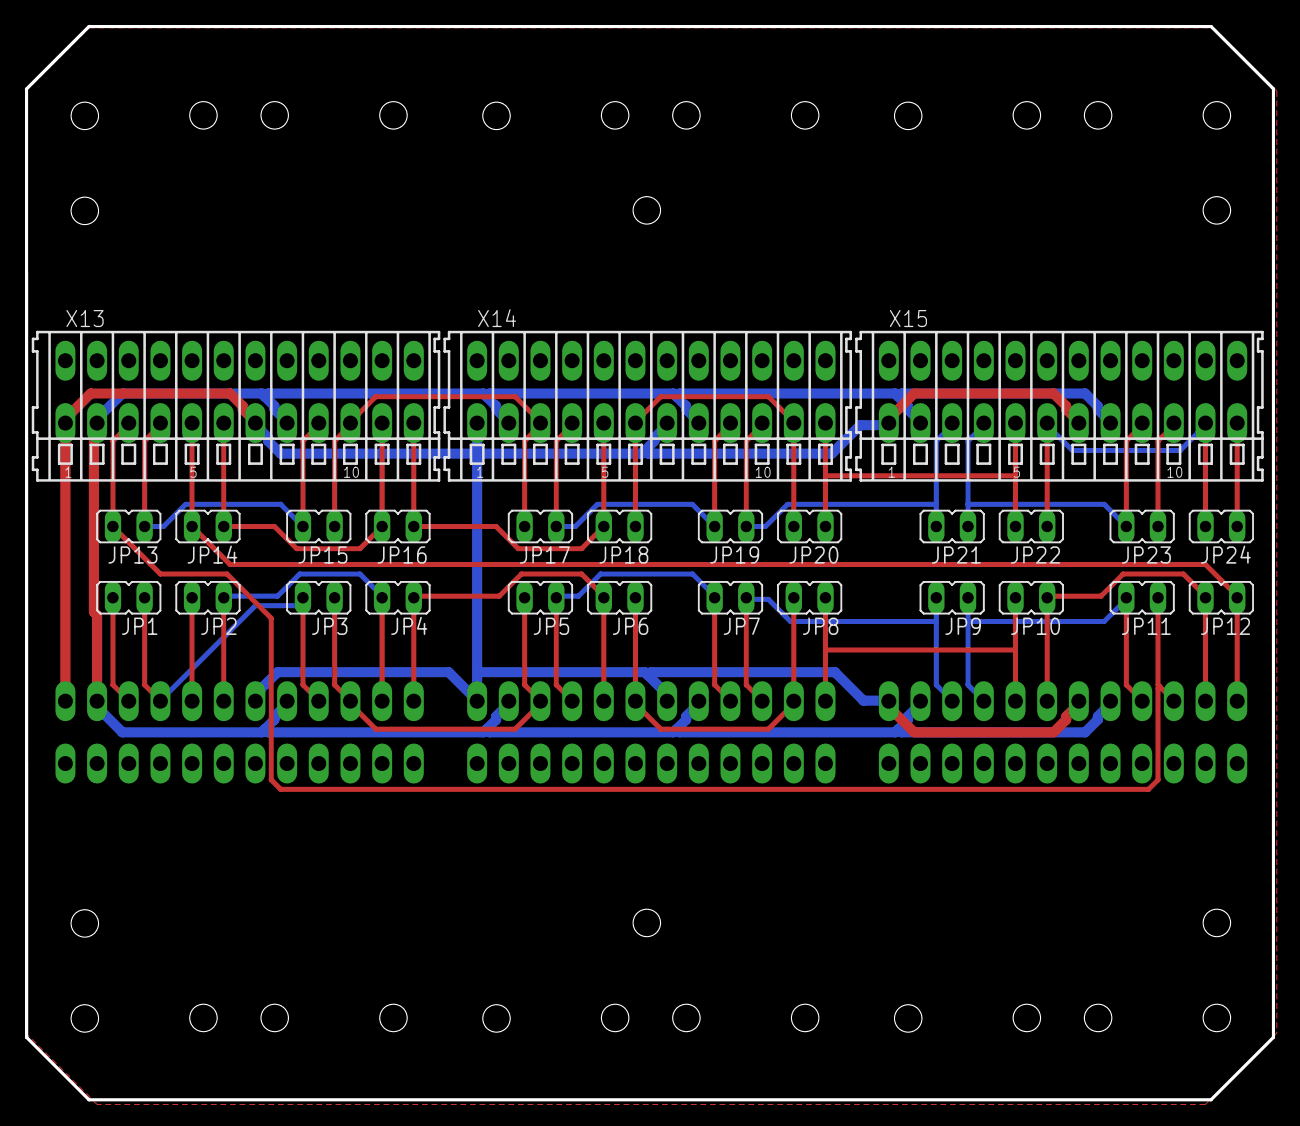
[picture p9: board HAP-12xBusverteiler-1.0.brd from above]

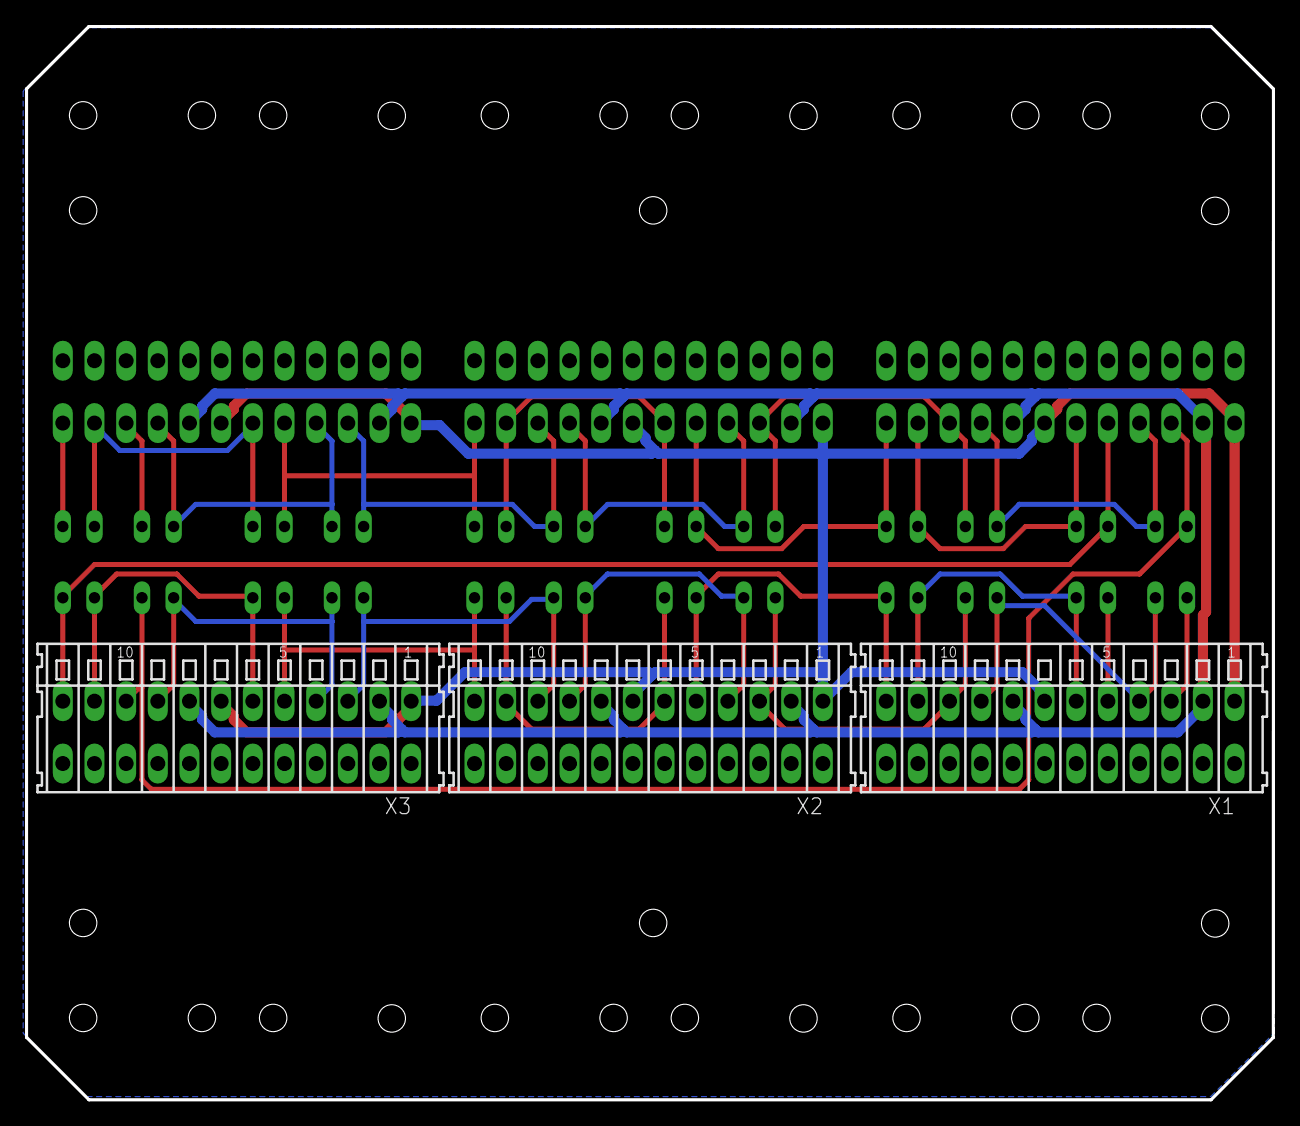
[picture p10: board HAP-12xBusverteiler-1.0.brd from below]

Board: 2 copper layers, 100.0 x 86.1 mm, 30 parts (3 on the bottom side), 28 nets.

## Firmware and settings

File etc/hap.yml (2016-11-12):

---
name: hapConfig

Model::hapModel:
  schema_class: hapConfig::hapSchema
  connect_info:
    - dbi:mysql:hap
    - 'hap'
    - 'password'
    - mysql_enable_utf8: 1
      on_connect_do:
        - SET NAMES 'utf8'
        - SET CHARACTER SET 'utf8'

BasePath: '/opt/hap'
FirmwareOutputPath: '/opt/hap/var/firmware'
Bootloader: '/opt/hap/var/bootloader/habl.hex'
WebStaticPath: '/opt/hap/var/static'
AVRPath: '/usr/local/avr'
AVRBinPath: '/usr/local/avr/bin'
MacroPath: '/opt/hap/var/macro'
LogFile: '/var/log/hap.log'
ScriptsPath: '/opt/hap/var/scripts'
CCUAddress: 1
ServerCU: 124
ServerCUConnection: 
  Type: 'Network'
  Host: 192.168.165.7
  Port: 10001
#ServerCUConnection:
#  Type: 'Serial'
#  Ports: [ '/dev/ttyUSB0', '/dev/ttyUSB1' ]
DefaultConfig: 1
MessageProcessor:
  Host: 127.0.0.1
  Port: 7891
Scheduler: 
  Host: 127.0.0.1
  Port: 7892  
MQTTBroker:
  Host: 127.0.0.1
  Port: 1883
HAPCmdLang: en
HAPCmdPrompt: 'HAP# '
Homematic:
  HmLanId : 'FFFFFF'
  HmLanIp: 192.168.165.49
  HmLanPort: 1000
  HmSecKey: '1122334455'
  HmVirtualId: 'ABCDEF'

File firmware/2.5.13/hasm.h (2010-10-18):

////////////////////////////////////////////////////////////////////////////////
// Projekt:              Home-Automation                                      //
// Modul:                Steuerung                                            //
// Version:              2.2 (6)                                              //
////////////////////////////////////////////////////////////////////////////////
// Erstellt am:          29.12.2005                                           //
// Erstellt von:         Holger Heuser                                        //
// Zuletzt geändert am:  05.02.2008                                           //
// Zuletzt geändert von: Holger Heuser                                        //
////////////////////////////////////////////////////////////////////////////////

#ifndef HASM
#define HASM


////////////////////////////////////////////////////////////////////////////////
// Module einbinden                                                           //
////////////////////////////////////////////////////////////////////////////////

#include <mv.h>

#include <hagl.h>


////////////////////////////////////////////////////////////////////////////////
// Precompiler Konstanten                                                     //
////////////////////////////////////////////////////////////////////////////////

#define SMIntIDNumberMask 0x0F
#define SMIntIDNumberBroadcast 0x0F
#define SMIntIDMediumMask 0x70
#define SMIntIDLB 0x00
#define SMIntIDFM 0x10
#define SMIntIDCB 0x20
#define SMIntIDMediumBroadcast 0x70
#define SMIntIDInvertMask 0x80
#define SMIntIDInvert 0x80
#define SMIntIDBroadcast 0x7F

#define SMMAUnconfigured 0x00
#define SMMAMulticast 0xF0
#define SMMABroadcast 0xFF

#define SMMTypeSet 0
#define SMMTypeSetAck 1
#define SMMTypeSetErr 2
#define SMMTypeQuery 8
#define SMMTypeQueryAck 9
#define SMMTypeQueryErr 10
#define SMMTypeStatus 16
#define SMMTypeStatusAck 17
#define SMMTypeStatusErr 18
#define SMMTypeMakro 24
#define SMMTypeMakroAck 25
#define SMMTypeMakroErr 26
#define SMMTypeEEPROM 28
#define SMMTypeEEPROMAck 29
#define SMMTypeEEPROMErr 30
#define SMMTypeControlProt 56
#define SMMTypeControlProtAck 57
#define SMMTypeControlProtErr 58
#define SMMTypeRawData 60
#define SMMTypeRawDataAck 61
#define SMMTypeRawDataErr 62
#define SMMTypeConfigIO 64
#define SMMTypeConfigIOAck 65
#define SMMTypeConfigIOErr 66
#define SMMTypeConfigIRAddr 68
#define SMMTypeConfigIRAddrAck 69
#define SMMTypeConfigIRAddrErr 70
#define SMMTypeConfigIRHotKeys 72
#define SMMTypeConfigIRHotKeysAck 73
#define SMMTypeConfigIRHotKeysErr 74
#define SMMTypeControl 76
#define SMMTypeControlAck 77
#define SMMTypeControlErr 78
#define SMMTypeConfigIRTrans 80
#define SMMTypeConfigIRTransAck 81
#define SMMTypeConfigIRTransErr 82
#define SMMTypeConfigIRLearn 84
#define SMMTypeConfigIRLearnAck 85
#define SMMTypeConfigIRLearnErr 86
#define SMMTypeDisplayData 88
#define SMMTypeDisplayAck 89
#define SMMTypeDisplayErr 90
#define SMMTypeDisplayControl 91
#define SMMTypeConfigAM 96
#define SMMTypeConfigAMAck 97
#define SMMTypeConfigAMErr 98
#define SMMTypeConfigAS 100
#define SMMTypeConfigASAck 101
#define SMMTypeConfigASErr 102
#define SMMTypeTCSet 120
#define SMMTypeTCSetAck 121
#define SMMTypeTCSetErr 122
#define SMMTypeTCSynchReq 123
#define SMMTypeMagicPacket 124
#define SMMTypeMagicPacketAck 125
#define SMMTypeMagicPacketErr 126
#define SMMTypeProtErr 127

#define SMSCIndexLow 128
#define SMSCStatusInvert 128
#define SMSCPlus 129
#define SMSCMinus 130
#define SMSCAllOn 131
#define SMSCAllOff 132
#define SMSCControlUp 133
#define SMSCControlDown 134
#define SMSCControlStop 135
#define SMSCControlStart 136
#define SMSCLeft 137
#define SMSCRight 138
#define SMSCPressShort 139
#define SMSCPressMedium 140
#define SMSCPressLong 141
#define SMSCRefresh 142
#define SMSCIndexHigh 142
#define SMSCNOP 255

#define SMPECNoResponse 1
#define SMPECDeviceBusy 2

#define SMEnquirerGUI 0xFF

#define SMControllerGUI 0x01
#define SMControllerIR 0x02
#define SMControllerEnd 0x02


////////////////////////////////////////////////////////////////////////////////
// Typdefinitionen                                                            //
////////////////////////////////////////////////////////////////////////////////

#ifdef COHAIR
typedef struct {
  tByte Modul;
  tByte Addr;
} tSMIOAddr;
#endif

typedef struct {
  tByte ModulAddress;
  tWord MulticastGroups;
  tByte CCUAddress;
  tByte RecBufferLength;
  tByte BridgeMode;
  tByte TimeServer;
#ifdef COHAIR
  tSMIOAddr IRAddr[100];
  tWord IRHotKeys[10];
#endif
} tSMC;

#ifdef COHAIR
typedef struct {
  tByte Length;                        // Laenge des eingegebenen Codes (ohne Enter)
  tByte Code[10];                    // Code-Array
} tSMIRKeyCodeComplete;
#endif


////////////////////////////////////////////////////////////////////////////////
// Deklarationen                                                              //
////////////////////////////////////////////////////////////////////////////////

void SMSystemReset(void);
void SMResetExt(void);
inline tSMC *SMGetConfPointer(void);
void SMSetConfDefaults(void);
void SMInit(void);
inline tByte SMGetModulAddress(void);
inline tByte SMGetBridgeMode(void);
#ifdef COHAER
inline void SMResetCounterInc(void);
inline void SMResetCounterReset(void);
#endif
inline void SMExtSteuerStatusTimeoutDec(void);
inline void SMExtQueryStatusTimeoutDec(void);
void SMRecBufAdd(tByte pInt, const tMData *pData);
void SMSendStatus(tByte pModul, tByte pAddr, tWord pValue, tByte pExt);
void SMSendZMSynchReq(void);
void SMSendMakro(tWord pMakro);
#ifdef COHAIR
void SMSendIRLearnReady(tByte pModul, tByte pMType, tByte pDevAddr, tByte pIndex, tByte pTranslate);
#endif
void SMSendProtErr(tByte pCode, tByte pValue0, tByte pValue1, tByte pValue2);
void SMGetInput(tByte pEnquirer, tByte pModul, tByte pDevice, tByte pSelect, tMDataCode *pMData);
void SMSetOutput(tByte pModul, tByte pDevice, tByte pHW, tWord pDelay, tMDataCode *pMData);
void SMProcessMess(void);
#ifdef COHAIR
void SMIRReceive(tSMIRKeyCodeComplete pKC);
#endif
inline void SMDestroy(void);


#endif

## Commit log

2010-01-20 Initial commit.
    [HAP-4xJalousieaktor-1.0.brd, HAP-4xJalousieaktor-1.0.sch, HAP-5xDimmer-3.1.brd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]
2010-01-25 Triggerwerte der Digital- u. Analogeingänge nicht als Messwerte in die DB schreiben.
2010-01-28 Rollosteuerung: gleichzeitige Aktivierung von Up- u. Down-Device wird jetzt verhindert
2010-09-02 [GUI] Update auf Extjs 3.2.1. Bugs im Zusammenhang mit dem Update behoben. Weitere kleine Fixe. Anpassung der Startscripte für Catalyst 5.8.
    [hap.yml]
2010-09-23 Update der Draw2d-Library. Javascript-Fehler im IE8 behoben. Anpassung Draw2d-Lib (setDimension aus constructor-Aufruf der figure.js entfernt)
2010-09-23 Komprmierte Version der Javascript-Dateien hinzugefuegt (hap-min) Tippfehler in Chart-Modul entfernt.
2010-10-02 Weitere Tippfehler im AS-Controller bei den Timern entfernt. (Evt. durch Autoformatierung entstanden?)
2010-10-08 [GUI] Chart5: HProgress, VProgress, Meter und Odometer funktionieren jetzt
2010-10-11 [GUI] Macro-Template hinzugefuegt. Bug in Context-Menues der Trees behoben. Button-Templates hinzugefuegt.
2010-10-12 [GUI] Der aktuell aktive Trigger wird jetzt in der GUI angezeigt.
2010-10-13 [GUI] Neben dem Offset fuer Charts kann jetzt auch der Intervall angegeben werden. Also z.B. Offset=14400 (24h) Interval=60 (1h) -> gibt alle werte von vor 24 bis vor 23 h an.
2010-10-18 Fehler beim setzen der Startzeit der AS Timer behoben (1)
2010-10-18 Fehler beim setzen der Startzeit der AS Timer behoben (2)
2010-10-18 [GUI] Neues AS-Device um Makros auf dem Server aufzurufen. Setzt eine angepasste Firmware voraus! (1)
2010-10-18 Unterstützung des neuen Makro AS-Device.
2010-10-21 Erweiterung der Statusanzeige für z.B. Reed-Eingängen (On=132, Off=4). Der Schwellwert für das On- u. Off-Icon kann über "On-Icon-Value" und "Off-Icon-Value" angegeben werden. Der Wert 0 aktiviert di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
2010-11-26 [GUI] Trigger-Status-Meldungen werden nicht mehr in die Status-Tabelle geschrieben.
2010-11-29 4x Polwender hinzugefuegt.
    [HAP-4xPolwender-1.0.brd, HAP-4xPolwender-1.0.sch]
2011-08-08 Statusdaten der GUI ueber ID selektieren.
2011-08-12 Aktuellen Helligkeitswert fuer die Invertierungsfunktion auch dann speichern, wenn die Helligkeit direkt ueber ein Kommando gesetzt wird.
2011-10-10 Skript wird bei Statusmeldung ueber Multicast gestartet
2011-11-07 Der letzte Status eines Devices bleibt immer in der Tabelle Status erhalten.
2011-11-14 controller_test.t und controller_test1.t wegen svn-checkout-Problemen entfernt
2011-11-21 Fehler im Timer(m)-Objekt der autonomen Steuerung behoben
2011-12-16 Die Helper-Scripte hap-sendcmd und hap-sendcmd2 senden jetzt 5 Retransmits, wenn eine Antwort ausbleibt. Das sollte bei instabilen Funk-Verbidungen helfen.
2013-01-29 Busverteiler Board
    [HAP-12xBusverteiler-1.0.brd]
2013-01-29 Busverteiler Schema
    [HAP-12xBusverteiler-1.0.sch]
2013-01-29 Removed file (wrong upload-path)
    [HAP-12xBusverteiler-1.0.brd]
2013-03-03 Added Homematic window rotary handle sensor, push-button 2-channel surface mount, indoor motion-indicator Fixed some bugs in homematic-stuff Added GUI-Stuff for Makro-By-Datagram-stuff
    [hap.yml]
2013-03-09 Modified Homematic-Channel-Handling for Homematic-Devices with more than one channel
2013-11-23 Added Homematic-Device HM-LC-Sw1-FM
2013-12-01 Added Homematic-Device HM-Sen-MDIR-O (Outdoor motion detector)
2014-11-10 Added Homematic 4x Actor (PCB-Version)
2016-11-12 Added MQTT-Gateway-Daemon: Publishes every HAP-device-state as /hap/module/device/status You can change a device state by sending values to /hap/module/device Also added a script for creationg openha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
